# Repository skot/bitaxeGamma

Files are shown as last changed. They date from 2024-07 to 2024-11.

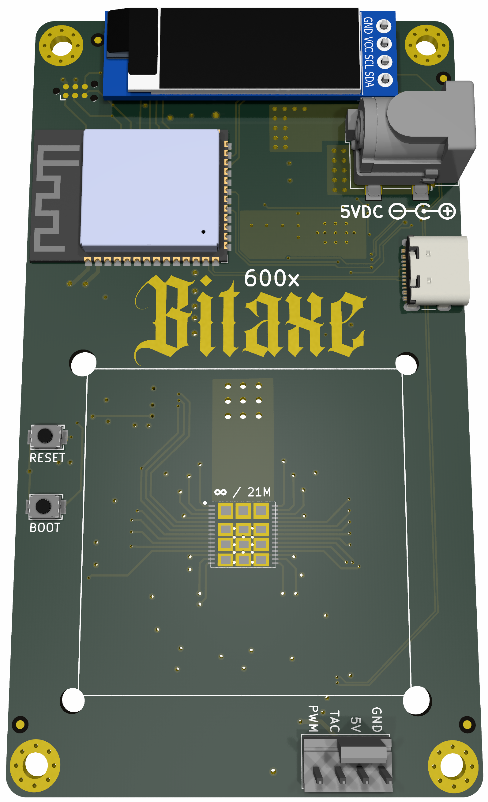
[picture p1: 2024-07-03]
doc/render.png

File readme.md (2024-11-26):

```
Open Source is Intrinsic to Bitcoin
```
# The bitaxeGamma
bitaxe is a fully open source Bitcoin ASIC miner aimed at decentralizing mining. bitaxeGamma is the 5th major revision of the bitaxe that now includes the BM1370 ASIC from the Antminer S21 Pro

bitaxeUltra assembled

## Goals
- **Easy**: Just plug it in and mine Bitcoin over WiFi. No external computer needed.
- **Practical**: low cost, low noise, low power, low maintenance. You can run this at home.
- **ASIC Power**: High efficiency and hashrate, based on the latest and greatest Application Specific Integrated Circuits.
- **Versatile**: Mine to any StratumV1 pool, Lottery mine, Solo mine, Or hack it to do whatever you want.
- **Bitcoin Ethos**: Fully open source, permissionless and decentralized to support the worldwide freedom money.

## ASIC
At the heart of the bitaxeGamma is a BM1370 Bitcoin mining ASIC from the Antminer S21 Pro from Bitmain. It's not open source.

- Bitmain claims the BM1370 has 15 J/TH efficiency. We can get pretty close to that with the BitaxeGamma
- The Antminer S21 Pro has a nominal hashrate of 234 TH/s. There are 3 hashboards with 65 chips each, for a total of 195 chips. The bitaxeGamma has a single one of these chips. That means _about_ 1.2 TH/s per bitaxeGamma. Initial testing looks good!
- The BM1370 is brand new and isn't available individually yet. The best place to get these chips is right out of a S21 Pro.
- The BM1370 has a different footprint and pinout from the BM1368, BM1366, BM1397 and BM1387 in previous bitaxe.

## Current Status
- BitaxeGamma 600 is working well and has been released!
- In addition to higher hashrate, the Gamma also uses more power. Please pay attemtion to hash frequency and voltage settings as it's much easier to overheat, especially when using the stock heatsink and fan.
- BM1370 firmware support has been added to [esp-miner](https://github.com/skot/esp-miner)
- Be sure to check the [HW issues](https://github.com/skot/bitaxe/issues) for known bugs, reworks and errata.
- This is an _advanced_ build! You can do it, but if you're not looking for a project, it might be best to buy one pre-assembled from one of the [many sellers](https://bitaxe.org/legit.html). Check [Skot's method](assembly.md) of hand assembling PCBs.

## PCB Hardware
This repo contains all of the design files for the PCB. [KiCAD](https://www.kicad.com) software is used. There is a BOM file for all of the components that get soldered to the PCB. 

- Order PCBs from your favorite PCB shop, like [JLCPCB](https://jlcpcb.com), [SeeedStudio](https://www.seeedstudio.com/fusion_pcb.html), or [PCBWay](https://www.pcbway.com)
    - Gerbers are in the `Manufacturing Files` dir. PCBs are 4-layer, 6mil trace/space and 0.3mm hole compatible. 1oz outer / 0.5oz inner layer thickness works well.
    - Make sure to order stencils too. These are the "paste" layers in the gerbers folder. one for top and one for bottom.
- All PCB parts except the ASIC are available from [DigiKey](https://www.digikey.com/en/products) and others. You can find Digikey part numbers on the DK tab of the BOM

## Extra Hardware
There are a few other hardware components that are needed for a complete bitaxe.

- **Heatsink**
	- [40x40mm heatsink and 5V fan](https://www.aliexpress.com/item/2251832861666365.html) from a random AliExpress seller. The fans are crap, but the heatsinks are good.  
- **Fan**
	- You **must** have active cooling on the bitaxe. The heatsink alone is not enough.
	- The Bitaxe has a connector for a 4pin, 5V PWM fan. 40mm square, 20mm thick fans work nicely with the suggested heatsink. Make sure to get a 5V fan! 12V spin, but slowly overheating your Bitaxe..
	- Upgrade your fan with the [Noctua NF-A4x10](https://noctua.at/en/nf-a4x10-5v-pwm) 5V 4-Pin fan for a much more pleasant experience.
- **Thermal compound**
	- Use a good quality thermal compound between the heatsink and ASIC. [Thermal Grizzly Kryonaut](https://www.amazon.com/Thermal-Grizzly-Kryonaut-Grease-Paste/dp/B011F7W3LU) has been known to work well.  
- **Display**
	- Supports 0.91" SSD1306-based I2C OLED Module. [Example Amazon seller](https://www.amazon.com/gp/product/B08ZY4YBHL). Make sure to get the male pins to interface with the Bitaxe PCB. 
- **Power Supply**
	- **5V DC Only!** Anything else will damage the Bitaxe. Be careful and double-check your power supply is 5V. Many other voltage power supplies use the same connector.
	- The power supply needs to supply in excess of 4A (20W) and not drop below 5V. Often times you have to use a power supply rated for 25-30W to get this!
 		- The [Meanwell GST60A05-P1J](https://www.digikey.com/en/products/detail/mean-well-usa-inc/GST60A05-P1J/7703709) at 30 Watts is the cadillac of 5V PSUs and is working well with the Gamma.  
	- The bitaxe uses a 5.5x2.1mm, center-positive barrel jack. 5.5x2.5mm plugs have been known to work.
- **Stand**
	- The PCB has corner mounting holes. You're going to want a stand to mount your Bitaxe. Many excellent 3D printed designs are available.

## Firmware
- The [ESP-Miner](https://github.com/skot/ESP-Miner) has initial support for the BM1370 ASIC. Improvements are ongoing.

### ESP32 Programming Requirements
- As of the bitaxeUltra, all ESP32 programming is done through a USB-C cable and connector on the bitaxe. See [ESP-Miner](https://github.com/skot/ESP-Miner) for more details.

## More Information
- Project page at [bitaxe.org](https://bitaxe.org)
- [Open Source Miners United](discord.gg/osmu) Discord chat
- [building.md](building.md) for PCB ordering tips
- [assembly.md](assembly.md) for assembly tips

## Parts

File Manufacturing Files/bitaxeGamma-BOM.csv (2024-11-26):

Qty | Reference | Value | PARTNO | DK | LCSC | DNP
1 | C6 | 4700pF | GRM155R71E472KA01D | 490-1309-1-ND
1 | C9 | 2200pF | GRM155R61H222KA01D | 490-8257-1-ND
1 | C10 | 4.7uF | GRM155R61A475MEAAD | 490-14306-1-ND
1 | C11 | 1000pF | CC0805KRX7R9BB102 | 311-1127-1-ND
1 | C13 | 100pF | 885012005013 | 732-7431-1-ND
1 | C50 | 470pF | CL05B471KB5NNNC | 1276-1566-1-ND
24 | C1 C5 C7 C21 C22 C23 C26 C27 C28 C30 C31 C32 C33 C34 C35 C36 C39 C40 C41 C42 C44 C45 C46 C48 | 1uF | EMK105BJ105MV-F | 587-5514-1-ND
3 | C14 C15 C16 | 22uF | GRM21BR61A226ME44L | 490-10746-1-ND
5 | C17 C18 C19 C20 C43 | 100uF | CL31A107MQHNNNE | 1276-1782-1-ND
2 | C2 C24 | 10uF | CL21A106KOQNNNE | 1276-1096-1-ND
3 | C3 C4 C51 | 47uF | CL32A476KOJNNNE | 1276-3376-1-ND
10 | C8 C12 C25 C29 C37 C38 C47 C49 C52 C53 | 0.1uF | CL05A104KO5NNNC | 1276-1234-1-ND
1 | J1 | 54-00164 | 54-00164 | 839-54-00164CT-ND | C431534
1 | J5 | USB_C_Receptacle_USB2.0 | USB4105-GF-A | 2073-USB4105-GF-ACT-ND
1 | J6 | Conn_01x04 | 0470531000 | WM4330-ND
1 | J7 | Conn_01x04
1 | L1 | 300nH | SLC1175-301MEC
1 | R1 | 8.25k | RC0402FR-078K25L | 311-8.25KLRCT-ND
1 | R5 | 14.7k | RC0402FR-0714K7L | YAG2984CT-ND
1 | R6 | 0 | RC0402JR-070RL | 311-0.0JRCT-ND
1 | R8 | 3.74k | RC0402FR-073K74L | 311-3.74KLRCT-ND
1 | R9 | 11.8k | RC0402FR-0711K8L | YAG2958CT-ND
1 | R10 | 68.1k | RC0402FR-0768K1L | YAG3213CT-ND
1 | R11 | 10 | RC0402FR-0710RL | 311-10.0LRCT-ND
1 | R12 | 1 | CSR1206FT1R00 | CSR1206FT1R00CT-ND
1 | R19 | 1k | RC0402FR-071KL | 311-1.00KLRCT-ND
1 | R21 | 20k | RC0402FR-0720KL | 311-20.0KLRCT-ND
1 | R24 | 5.6k | RC0402FR-135K6L | 13-RC0402FR-135K6LCT-ND
2 | R13 R14 | 49.9 | RC0402FR-0749R9L | 311-49.9LRCT-ND
4 | R15 R16 R17 R25 | 10k | RC0402JR-0710KL | 311-10KJRCT-ND
2 | R22 R23 | 100 | RC0402FR-07100RL | 311-100LRCT-ND
2 | SW1 SW2 | GT-TC029B-H025-L1N | CS1213AGF260 | 2449-CS1213AGF260CT-ND
1 | U2 | TPS546D24ARVFR | TPS546D24ARVFR | 296-TPS546D24ARVFRCT-ND
1 | U3 | RT9080-33GJ5 | RT9080-33GJ5 | 1028-1509-1-ND
1 | U4 | ESP32-S3-WROOM-1 | ESP32-S3-WROOM-1-N16R8 | 1965-ESP32-S3-WROOM-1-N16R8CT-ND
1 | U5 | MCP1824T-1202E/OT | MCP1824T-1202E/OT | MCP1824T-1202E/OTCT-ND
1 | U6 | MCP1824T-0802E | MCP1824T-0802E/OT | MCP1824T-0802E/OTCT-ND
1 | U7 | 25MHz | SX3M25.000E20F30THN |  | C5137262
1 | U8 | BM1370_mode1
1 | U9 | SN74AVC4T774 | SN74AVC4T774PWR | 296-24739-1-ND
1 | U10 | EMC2101 | EMC2101-R-ACZL-TR | EMC2101-R-ACZL-CT-ND

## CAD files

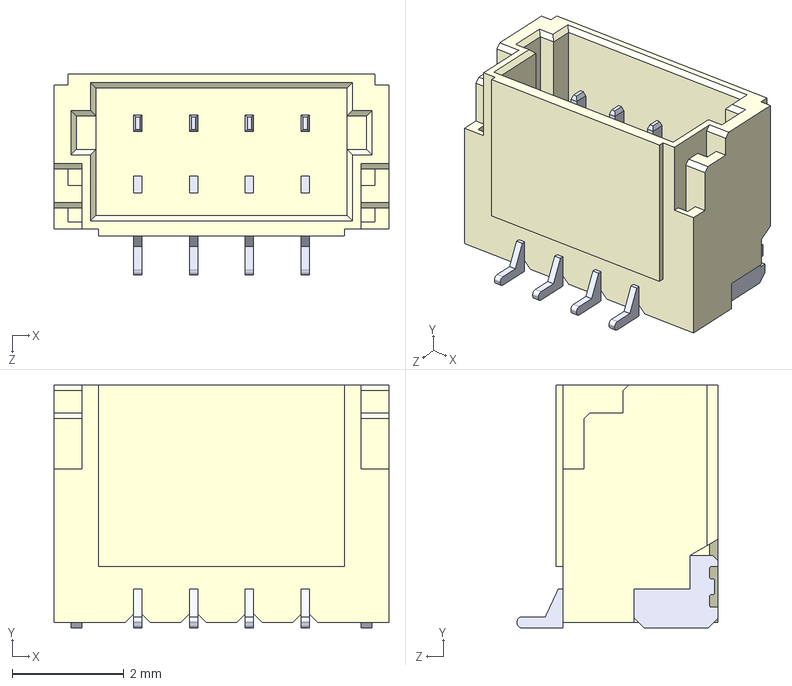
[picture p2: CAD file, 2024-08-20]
3d/BM04B-SRSS-TBT(LF)(SN)--3DModel-STEP-56544.STEP
6.00 x 4.35 x 3.60 mm

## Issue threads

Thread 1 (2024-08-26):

Components

marplukiwi, 2024-08-26:
Please check
The R18 and R19 are shown in the BOM list but the R18 is missing in the KiCAD 3D model. Does this have to be installed or not?

marplukiwi, 2024-08-26:
I noticed this in version 601 not 600

austrisv, 2024-10-07:
R18 in the 600 version's schematics is marked as DNP (Do Not Place). I guess it's a glitch in the generated BOM file.
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

austrisv, 2024-10-07:
Duplicate of https://github.com/skot/bitaxeGamma/issues/5

Closed 2025-03-03.

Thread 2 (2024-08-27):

Wrong display connector

marplukiwi, 2024-08-27:
The display Connector NPTC041KFXC-RC in the BOM File is wron

marplukiwi, 2024-08-27:
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

yellowpi, 2024-09-19:
And what is the truth? Did you find out?

yellowpi, 2024-09-19:
> 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

And what is the truth? Did you find out?

yellowpi, 2024-09-19:
> The display Connector NPTC041KFXC-RC in the BOM File is wron

And what is the truth? Did you find out?

marplukiwi, 2024-09-19:
I soldered the display directly to the PCB without a connector. This is also better because the display only has a small distance to the PCB and cannot bend.

yellowpi, 2024-09-19:
> I soldered the display directly to the PCB without a connector. This is also better because the display only has a small distance to the PCB and cannot bend.

Hello, you can use the screen reinforcement in the link below by printing it from your 3D printer and use it compatible with your screen.
 with love.

link

https://github.com/IamGPIO/Bitaxe201-204-ScreenSaver

skot, 2024-09-19:
Hey, sorry about that. There is no connector needed on the PCB for the display. Get a OLED with male pins and it will friction-fit into the holes on the Bitaxe PCB -- or you can solder them in.

I'll get this fixed on the BOM

yellowpi, 2024-09-19:
> Hey, sorry about that. There is no connector needed on the PCB for the display. Get a OLED with male pins and it will friction-fit into the holes on the Bitaxe PCB -- or you can solder them in.
>
> I'll get this fixed on the BOM

Mr. skot, is there no need to buy this? Should we buy this component?

skot, 2024-09-19:
J3 part number has been removed from schematic and BOM. There is no need for a part on this footprint.

Closed 2024-09-19.

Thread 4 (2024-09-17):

R2, R3, R4 and R7

Alexgtc, 2024-09-17:
Does anyone know why the list of materials does not show the resistances r2, r3, r4 and r7 and in the gerbers yes? Can the plate be mounted leaving those resistors unmounted?

marplukiwi, 2024-09-19:
According to the circuit diagram, the resistors are not needed
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

Alexgtc, 2024-09-19:
Ok, so leaving those resistors without mounting, the gamma bitaxe should work without problems, right?

marplukiwi, 2024-09-19:
If the documentation, i.e. the circuit diagram, is correct then yes. But I cannot confirm this.

Alexgtc, 2024-09-19:
Ok, I'll try to mount it without those resistances to see if it works. Thank you for the help.

yellowpi, 2024-09-19:
@skot dear skot, what do you say about this?

skot, 2024-09-19:
@marplukiwi is correct, R2, R3, R4 and R7 are DNP meaning "Do Not Place".

marplukiwi, 2024-09-20:
@skot and R18 DNP or not? R18 is in the BOM but crossed out in the circuit diagram.

skot, 2024-09-20:
The red X in KiCad means DNP

Closed 2024-09-19.

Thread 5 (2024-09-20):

R18

Alexgtc, 2024-09-20:
R18, is in the list of materials but it is crossed out in the diagrams. Should we install it in version 600?

skot, 2024-09-20:
Yes the red X in KiCad schematic means DNP

Closed 2024-09-20.

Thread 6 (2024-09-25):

unused level shifter inputs should not be left floating.

skot, 2024-09-25:
From the [SN74AVC4T774 datasheet](https://www.ti.com/lit/ds/symlink/sn74avc4t774.pdf)

> Since this device has CMOS inputs, it is very important to not allow them to float. If the inputs are not driven to either a high VCC state, or a low-GND state, an undesirable larger than expected ICC current may result. Since the input voltage settlement is governed by many factors (for example, capacitance, board-layout, package inductance, surrounding conditions, and so forth), ensuring that they these inputs are kept out of erroneous switching states and tying them to either a high or a low level minimizes the leakage-current.

We need to either connect the input B4 to ground, or tie DIR4 high to make B4 an output.

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

skot, 2025-04-29:
this has been fixed.

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

Closed 2025-04-29.

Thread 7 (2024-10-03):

Switch from SN74AVC4T774 (AVC) SN74AXC4T774 (AXC)

benjamin-wilson, 2024-10-03:
The SN74AXC4T774  is a drop in replacement - I would also suggest using the WQFN package as it is more stocked and 2/3 the cost.
"The AXC is faster, has a wider supply range and guarantees glitch free power up."

https://www.ti.com/lit/ds/symlink/sn74axc4t774.pdf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

person65278, 2025-02-02:
so what would happen if i swapped  it to SN74AXC4T774PWR from digi key. just unsoldered the old and slapped it on there?

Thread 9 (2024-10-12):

DFM - Increase pad size of barrel plug and inductor

benjamin-wilson, 2024-10-12:
Increase the pad size of these two elements to provide more solder to the component - the barrel plug can be removed with a strong push of the thumb currently.

4xmajor, 2024-10-15:
I have a few more suggestions/observations regarding these these parts...

1. Due to availability issues, I switched the barrel jack suggested in the schematic (54-00164) out for  PJ-036AH-SMT-TR.

The pads and contacts are far more substantial than the 54-00164, and it is far more abundantly available (on DigiKey at least)... may be a better choice in general?

2. I also have had to switch out the suggested inductor (SLC1480-301ML) to 104CDMCCDS-R30MC due to availability issues.

The package size and footprint of the SLC1480-301ML is very awkward. It is basically unique among inductors which satisfy the calculated necessary values for L, Isat and Irms according to the TPS546D24 datasheet (8.2.2.3). (I got: L = 300nH, Irms = 35.12A, Isat(peak) = 40.02A)

The package size of 104CDMCCDS-R30MC seems to be very common for these attributes at 11.5mm x 10mm. This might be a better choice for the schematic as it promotes drop-in replacements and also happens to require larger solder pads for sturdiness.

skot, 2024-10-21:
> I have a few more suggestions/observations regarding these these parts...
>
> 1. Due to availability issues, I switched the barrel connector suggested in the schematic (54-00164) out for  PJ-036AH-SMT-TR.

funny story; we switched to 54-00164 previously because PJ-036AH-SMT-TR went 100% out of stock everywhere. It's wack-a-mole with these things.

BitMaker-hub, 2024-10-22:
I also think 54-00164 is more standard, we can go furder and find compatible parts to it also. Sure there are more out there

benjamin-wilson, 2024-11-02:
Did this on 602 - sent to fab for verification

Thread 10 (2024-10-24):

BOM change U7

BitMaker-hub, 2024-10-24:
Hi Skot,

Seems previously used crystal 25,0-JO32-B-1V3-1-T1-LF is out of voltage range currently used in GAMMA.
BOM still says 25,0-JO32-B-1V3-1-T1-LF ofr U7.

Can you change it to SX3M25.000E20F30THN, to avoid others mistake?

skot, 2024-10-24:
This is a really unfortunate CSV parsing error. I've fixed it in the 600 release already. I think it might still need to be fixed in the unreleased branches

Closed 2025-03-03.

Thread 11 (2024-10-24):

Suggestion - TVS diode at 5V input

BitMaker-hub, 2024-10-24:
Even could not be necessary, this is recommended to protect bitaxe from plug/unplug transients.
This should be on the power supply, but you can't always guarantee.

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

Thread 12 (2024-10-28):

Some bitaxeGamma builds are overheating at stock settings.

skot, 2024-10-28:
We have reports of some bitaxeGamma 600 builds overheating in a few minutes with recommended stock heatsink and fan, running at stock settings of 525MHz / 1150mV

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

skot, 2024-10-28:
There are plenty of bitaxeGamma 600/601/602 that are not overheating at stock settings, including the dozen or so I have used.

skot, 2025-03-03:
This has been fixed with better temp diode tuning on the EMC2101

Closed 2025-03-03.

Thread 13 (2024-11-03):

Determine proper ASIC temp diode series resistance

skot, 2024-11-03:
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

R22 and R23 are series resistors inline with the ASIC temp diode, used for measuring the ASIC die temp.

The [EMC2101 datasheet](https://ww1.microchip.com/downloads/aemDocuments/documents/MSLD/ProductDocuments/DataSheets/EMC2101-Data-Sheet-DS20006703.pdf) says;

> Parasitic resistance in series with the external diodes will limit the accuracy obtainable from temperature measurement devices. The voltage developed across this resistance by the switching diode currents cause the temperature measurement to read higher than the true temperature. Contributors to series resistance are Printed Circuit Board (PCB) trace resistance, on die (i.e. on the processor) metal resistance, bulk resistance in the base and emitter of the temperature transistor. Typically, the error caused by series resistance is +0.7°C per ohm. Temperature errors caused by up to 100Ω of series resistance are automatically corrected.

Is 100 Ohms in series the right call? Maybe we don't need _any_ series resistance here? Does this have something to do with #12 ?

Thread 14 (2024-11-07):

BOM file missing some resistors

sospcie, 2024-11-07:
BOM file missing some resistors, like R2 , R3, R4, R7

austrisv, 2024-11-08:
check https://github.com/skot/bitaxeGamma/issues/4 - they are DNP, thus not placed in the BOM (as the resistors are not needed)

Closed 2025-03-03.

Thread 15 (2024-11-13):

some ASIC die temperature readings are incorrect

skot, 2024-11-13:
On some BM1370 units the die temperature readings collected by the EMC2101 are incorrect. We've seen readings both too high and too low. Both at idle and while mining.

Initially it appears some units are affected and others are not.

skot, 2024-11-13:
might be related to #13

skot, 2025-03-04:
This has been fixed with better temp diode tuning on the EMC2101

Closed 2025-03-04.

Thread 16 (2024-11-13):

Fluctuating ASIC die temperature readings.

skot, 2024-11-13:
A few users have reported wildly fluctuating ASIC die temperature readings, sometimes 20ºC or more between individual temperature readings.

skot, 2024-11-13:
from OSMU Discord user `usekevin`:
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

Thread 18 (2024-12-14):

Hole Pattern for heatsink is not symmetric

ogbitcoin, 2024-12-14:
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

skot, 2025-03-03:
This is a bug. They should be symmetric.

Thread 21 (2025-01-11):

Failure to find select PLL frequencies when overclocking

jtsmith0101, 2025-01-11:
Investingating higher frequencies.  On startup, there are several frequency failure messages above 750 MHz.  Please see attached.

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

Does this mean my hashing on a 600 gamma is capped?  Can it be fixed with a new firmware or does it indicate a hardware anomaly?

My firmware is v2.4.4

skot, 2025-03-03:
No your frequency is not capped. Due to the way (we think the) BM1370 registers work, not all frequencies are available. All that really matters here is that it can find the last one.

Closed 2025-03-03.

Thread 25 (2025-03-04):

Add pullup resistors on I2C/SMBus pins

skot, 2025-03-04:
SDA and SCL data pins need a pullup resistor to 3.3V. The TPS546 SMB_ALRT should also have this. 4.7k should be good.

sz4bi, 2025-05-14:
I can not find the SMB_ALRT resistor anywhere in the modified files. Are we talking about the TPS546 PMB_ALRT pin on the schematics?

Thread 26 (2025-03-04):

Improve BM1370 footprint.

skot, 2025-03-04:
The GND power pad is a little too big, and VDD too small. Also revisit the 0.503mm pin pitch. Should it be 0.50mm?

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

benjamin-wilson, 2025-03-05:
Fixed in this commit:
713e3acc43809ab757ac48d10b03d2d3deff822a
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

Closed 2025-03-16.

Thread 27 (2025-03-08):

Missing Resistors in BOM and Clarification on DNP Components

loden-nodeway, 2025-03-08:
To whom it may concern,

I noticed that the BOM list is missing several resistors: R2, R3, R4, R7, R18, R20, R22, and R23. After checking the schematic, I found that R2, R3, R4, and R7 are marked as DNP (Do Not Place). However, R18, R20, R22, and R23 do not appear to be DNP.

Could you please confirm if my observation is correct? Also, I would appreciate it if you could provide the component names for these resistors.

Thank you for your attention to this matter.

Best regards,
Loden.

Marcocanc, 2025-03-16:
+1

skot, 2025-03-16:
R2, R3, R4, R7, R18 are DNP on the schematic.
R20 doesn't exist
R22 & R23 are on the BOM: https://github.com/bitaxeorg/bitaxeGamma/blob/a325117698b93c3a2e064ae0e7f2b570a8666134/Manufacturing%20Files/bitaxeGamma-BOM.csv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

Closed 2025-03-16.

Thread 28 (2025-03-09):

Wrong part number for J3

adadnc, 2025-03-09:
On the board J3 is shown as a through-hole component while the part number from the schematics lists a NPTC041KFXC-RC, which is an SMD component. Am I wrong here? Either the footprint is wrong or is the part number.

skot, 2025-04-29:
fixed in 4bcb769

Closed 2025-04-29.

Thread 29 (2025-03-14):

Bitaxe Gamma Not Hashing

Kizzle65, 2025-03-14:
I have two Bitaxe Gammas and both setup up exactly the same.  The one is hashing but other will not.  Please help me out.

pinetree1212, 2025-03-14:
I had the same issue. While checking the DASHBoard on AxeOS, I noticed that the input voltage was higher than 5.2V. After replacing the adapter with a Korean-made one instead of a new Chinese one, it started hashing  Accurate voltage supply seems to be important

Kizzle65, 2025-03-14:
So now both of them won't hash. They are running 5.3 and 5.4 volts. Are you saying the voltage needs to be closer to 5.0?

Closed 2025-03-14.

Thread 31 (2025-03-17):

UVLO Voltage divider it set wrong for 5V input

skot, 2025-03-17:
The TPS546D24A UVLO threshold is 2.5V. For this to trigger at about 4.5VIN, R8 should by 15k (not 3.74k)

skot, 2025-03-18:
Er, maybe not. I think I was looking at the wrong threshold (there are several). The ENuvlo threshold is actually 1.05V, making the UVLO for our current voltage divider set at 4.36V

Closed 2025-03-18.

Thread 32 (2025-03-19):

PCB mounting holes are a bit off

etkaar, 2025-03-19:
They are only off a little bit, but that still can cause problems with custom stands, enclosures and cases:

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

skot, 2025-04-29:
fixed in 4bcb769

Closed 2025-04-29.

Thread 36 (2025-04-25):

ASIC nRST pin should be pulled down

skot, 2025-04-25:
nRST low -> ASIC in reset. this is what we want to be by default.

skot, 2025-04-29:
fixed in 4bcb769

Closed 2025-04-29.

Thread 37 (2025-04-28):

Bitaxe is not detected when connected to a USB-C port

rkuester, 2025-04-28:
A Bitaxe Gamma is not detected when connected to an upstream USB-C port. Presumably, this is due to lack of pull-downs on the Bitaxe's USB-C CC pins. USB Sources detect the attachment of devices through USB-C physical connections by utilizing the CC pins.

I have verified this behavior on both a modern MacBook Air and a Linux server with USB-C ports. Presumably, this would also be an issue with hubs that have USB-C ports facing downstream.

There is no issue when a Bitaxe is connected via a USB-C to USB-A cable, because USB-A ports detect attachment via devices pulling up D+ and or D- (in the Bitaxe's case, internally in the USB controller).

MyOwn2C, 2025-04-28:
Known issue but not fixed.
Only my oldest Ultra works with USB.
All my other Supra (2x) and Gamma (3x) none of them worked with USB.
I just use UART to update if webpage update does not work.

skot, 2025-04-28:
Uuuf, you are totally right. I'm kicking myself for removing these pulldowns a while back. I'll get these put back on in future revs. In the mean time you'll have to use a USB-C to USB-A adapter and cable 😭

I swear I had a USB-C to C cable that magically worked.

skot, 2025-05-12:
- Connect a 5.1 kΩ resistor from CC1 to ground.
- Connect a 5.1 kΩ resistor from CC2 to ground.

skot, 2025-07-03:
I have heard that Bitaxes works on USB-C ports that are not also Thunderbolt ports.

skot, 2025-07-03:
Confirmed adding 5.1k pulldown resistors on CC1 and CC2 on a BitaxeGamma 601 allows it to mount on my MacBook USB-C thunderbolt ports.

skot, 2025-09-10:
Looks like this bug was introduced on 401 hardware. everything prior to that _should_ be unaffected.

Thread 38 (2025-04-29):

Some silkscreen labels on 602 are all wonky

skot, 2025-04-29:
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

skot, 2025-04-29:
fixed in 4bcb769

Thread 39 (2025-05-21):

control the 4bit nonce.

g1ass1, 2025-05-21:
is there a way to control or limit how the device interacts with the mining loop.  specifically, the 4byte nonce in the block header.
I see how this can be done with extra nonce easily.  is the nonce controlled via asci hardware or the code.

skot, 2025-05-21:
there is some rudimentary control over the nonce range that the ASIC rolls through. This is used when the ASICs are in long chains so that they don't duplicate work.

This is the hardware repo, the [esp-miner](https://github.com/bitaxeorg/esp-miner) or even better the [OSMU Discord](https://discord.gg/osmu) would be more appropriate for this discussion.

Closed 2025-05-21.

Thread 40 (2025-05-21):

Bite Gamma

superfastdrop, 2025-05-21:
I have a new Gamma that's not hashing. The only issue I can see is there is 0 measured ASIC voltage. How can this be fixed?

skot, 2025-05-21:
Speak with the seller where you purchased your Bitaxe for support.

Closed 2025-05-21.

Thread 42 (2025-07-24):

Bitaxe Gamma stops working after wifi hickup

cedrickoch, 2025-07-24:
Description:
I've been operating a Bitaxe Gamma for a few weeks now and have encountered a recurring issue where it stops hashing every few days, requiring a restart. When the device enters this state, the web interface also becomes unreachable. I've logged the output from the USB interface, which is attached for review.

Observations:
- The initial part of the log shows everything working smoothly.
- In the middle of the log, there are multiple WiFi resets. It's worth noting that the WiFi repeater is positioned right next to the Bitaxe and is stable.
- The final phase in the log indicates when the Bitaxe stops functioning.

Steps to Reproduce:
- Operate the Bitaxe Gamma over several days.
- Observe the hashing process and periodically check accessibility to the web interface.
- Monitor for an eventual halt in operation and loss of web interface access.

Expected Outcome:
- Continuous hashing and accessible web interface without the need for frequent restarts.
- Actual Outcome: Hashing stops intermittently every few days, requiring a restart, and the web interface becomes unavailable during this period.

Attached Log: Please find the USB interface log attached for further investigation.

[debug.log](https://github.com/user-attachments/files/21402074/debug.log)

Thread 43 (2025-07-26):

BitAxe Gamma with duplicate share.

RoanArraes, 2025-07-26:
I need help with duplicate share in my BitAxe Gamma. I dont know how this happens.

How i can fix this?

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

111 rejected ( all duplicate share)

Log:

₿ (16791238) stratum_task: rx: {"result":false,"error":{"code":22,"message":"duplicate share","data":null},"id":1226}
₿ (16791238) stratum_task: message result rejected: unknown

₿ (17032038) stratum_task: rx: {"result":false,"error":{"code":22,"message":"duplicate share","data":null},"id":1248}
₿ (17032038) stratum_task: message result rejected: unknown

₿ (17147038) stratum_task: rx: {"result":false,"error":{"code":22,"message":"duplicate share","data":null},"id":1260}
₿ (17147038) stratum_task: message result rejected: unknown

Thanks for help.

RoanArraes, 2025-07-27:
I tried tree pools and two have the same duplicate share problem, but the third pool didn't show this problem.

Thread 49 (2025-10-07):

BOM List J1 DC Power Jack Incompatible

lrstolk, 2025-10-07:
I found out the advised J1 - DC Power Jack does actually not meet the requirements.

The CSV BOM list tells me to use LCSC part C431534. This is max 30V 2A. While the README tells me I need a power supply of 5V with 4A, this exceeds the power of what the DC Power Jack can hold.

Any advice of what to do? I already placed a pick and placed order on LCSC.

skot, 2025-10-07:
Uuf, sorry I didn't notice this before. The DigiKey part number is rated for 5.5A I've removed the LCSC part number from the BOM.

Maybe you can contact JLCPCB and have them DNP this part on your build?

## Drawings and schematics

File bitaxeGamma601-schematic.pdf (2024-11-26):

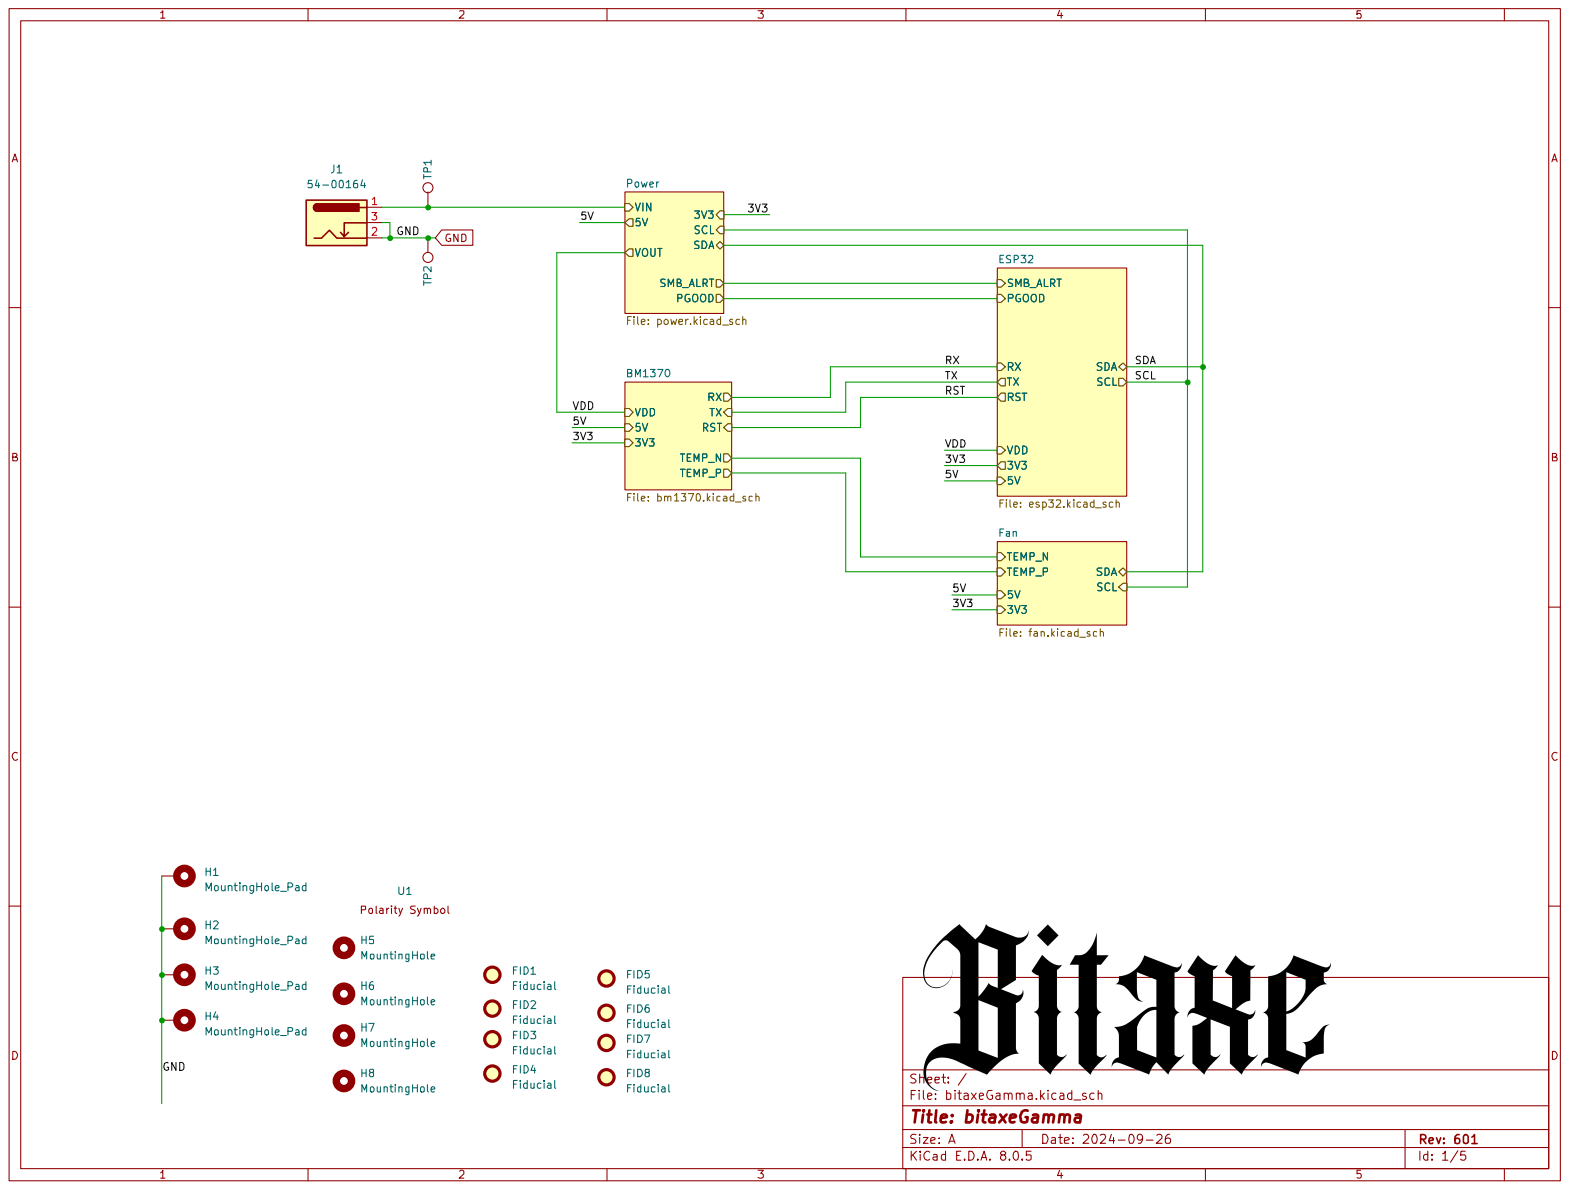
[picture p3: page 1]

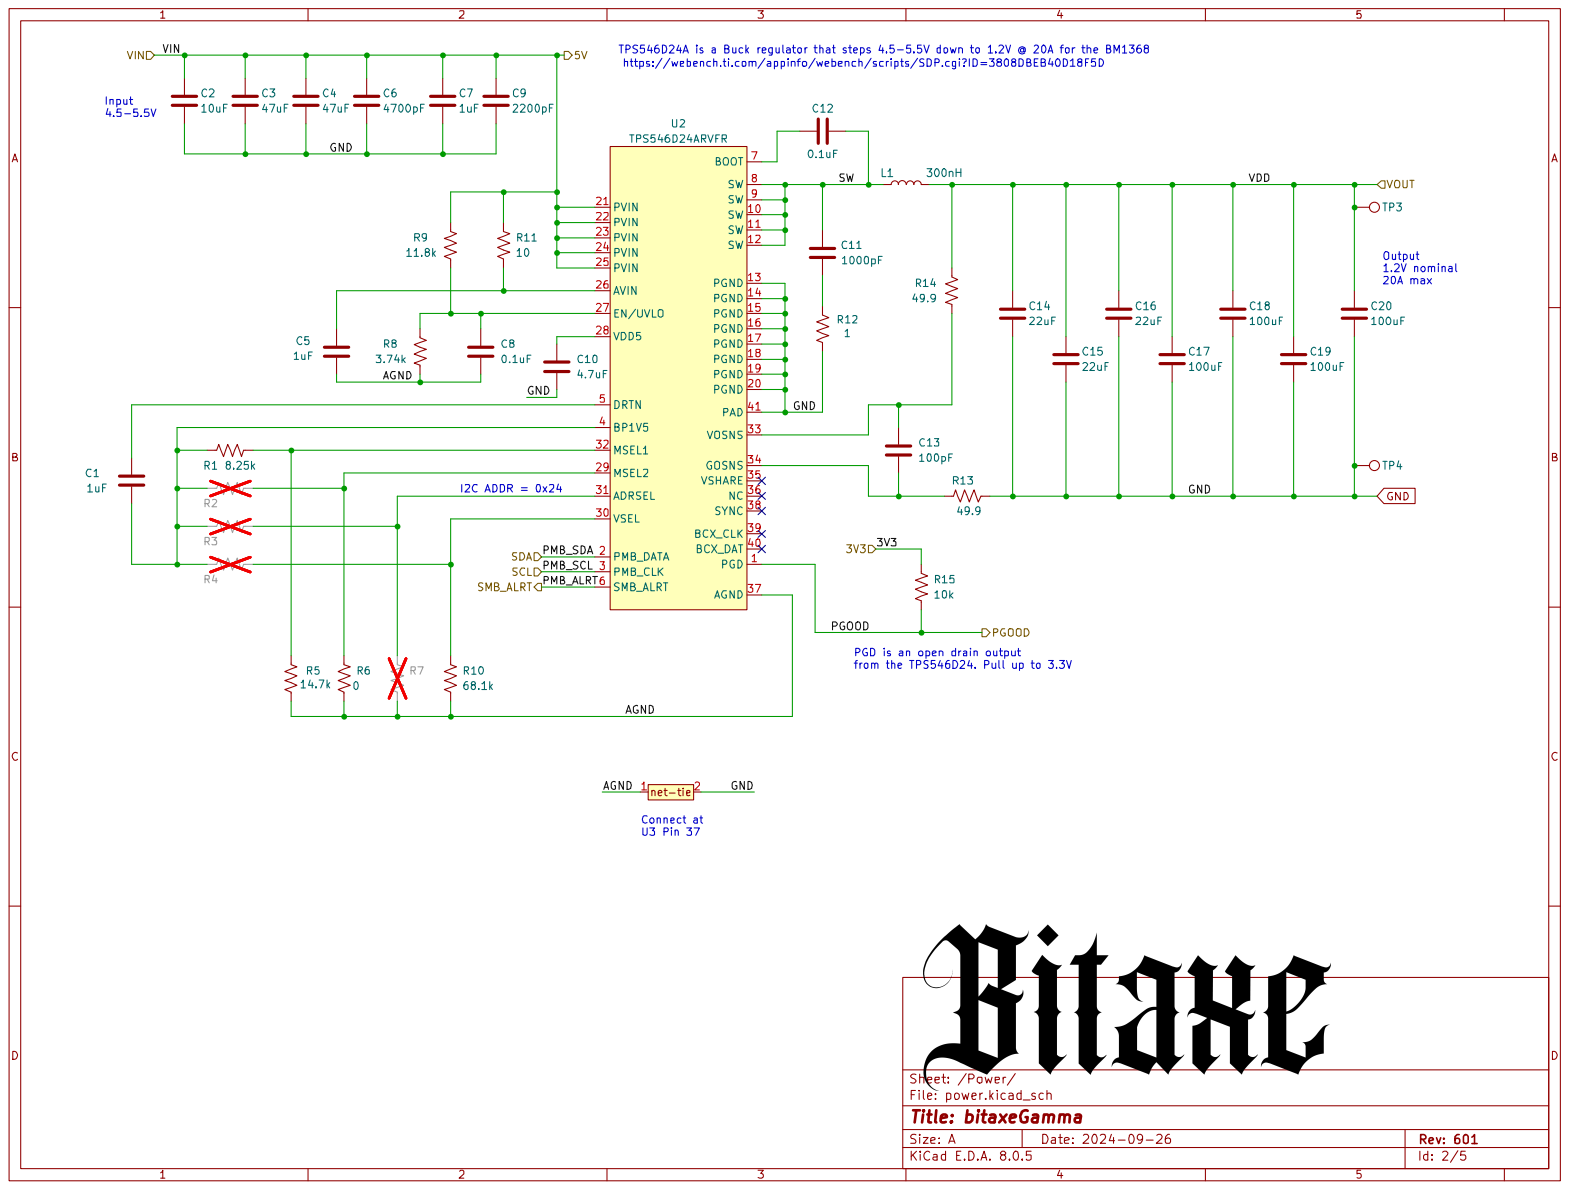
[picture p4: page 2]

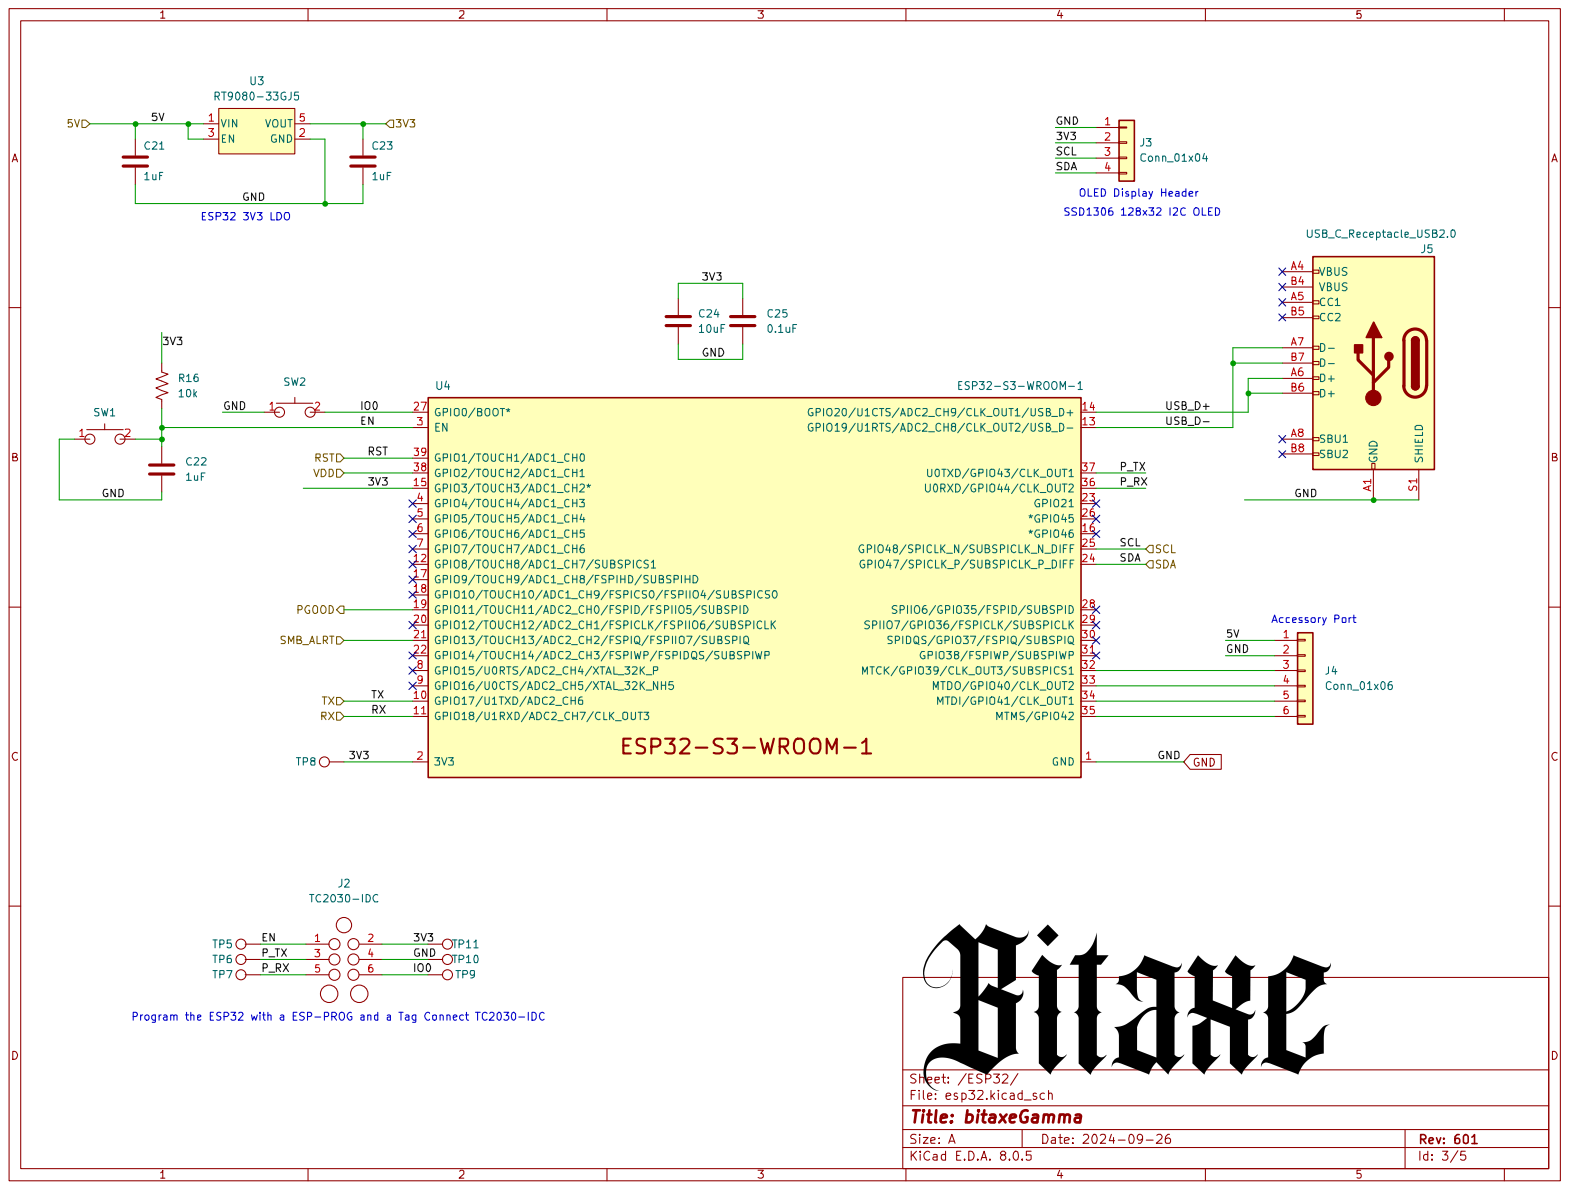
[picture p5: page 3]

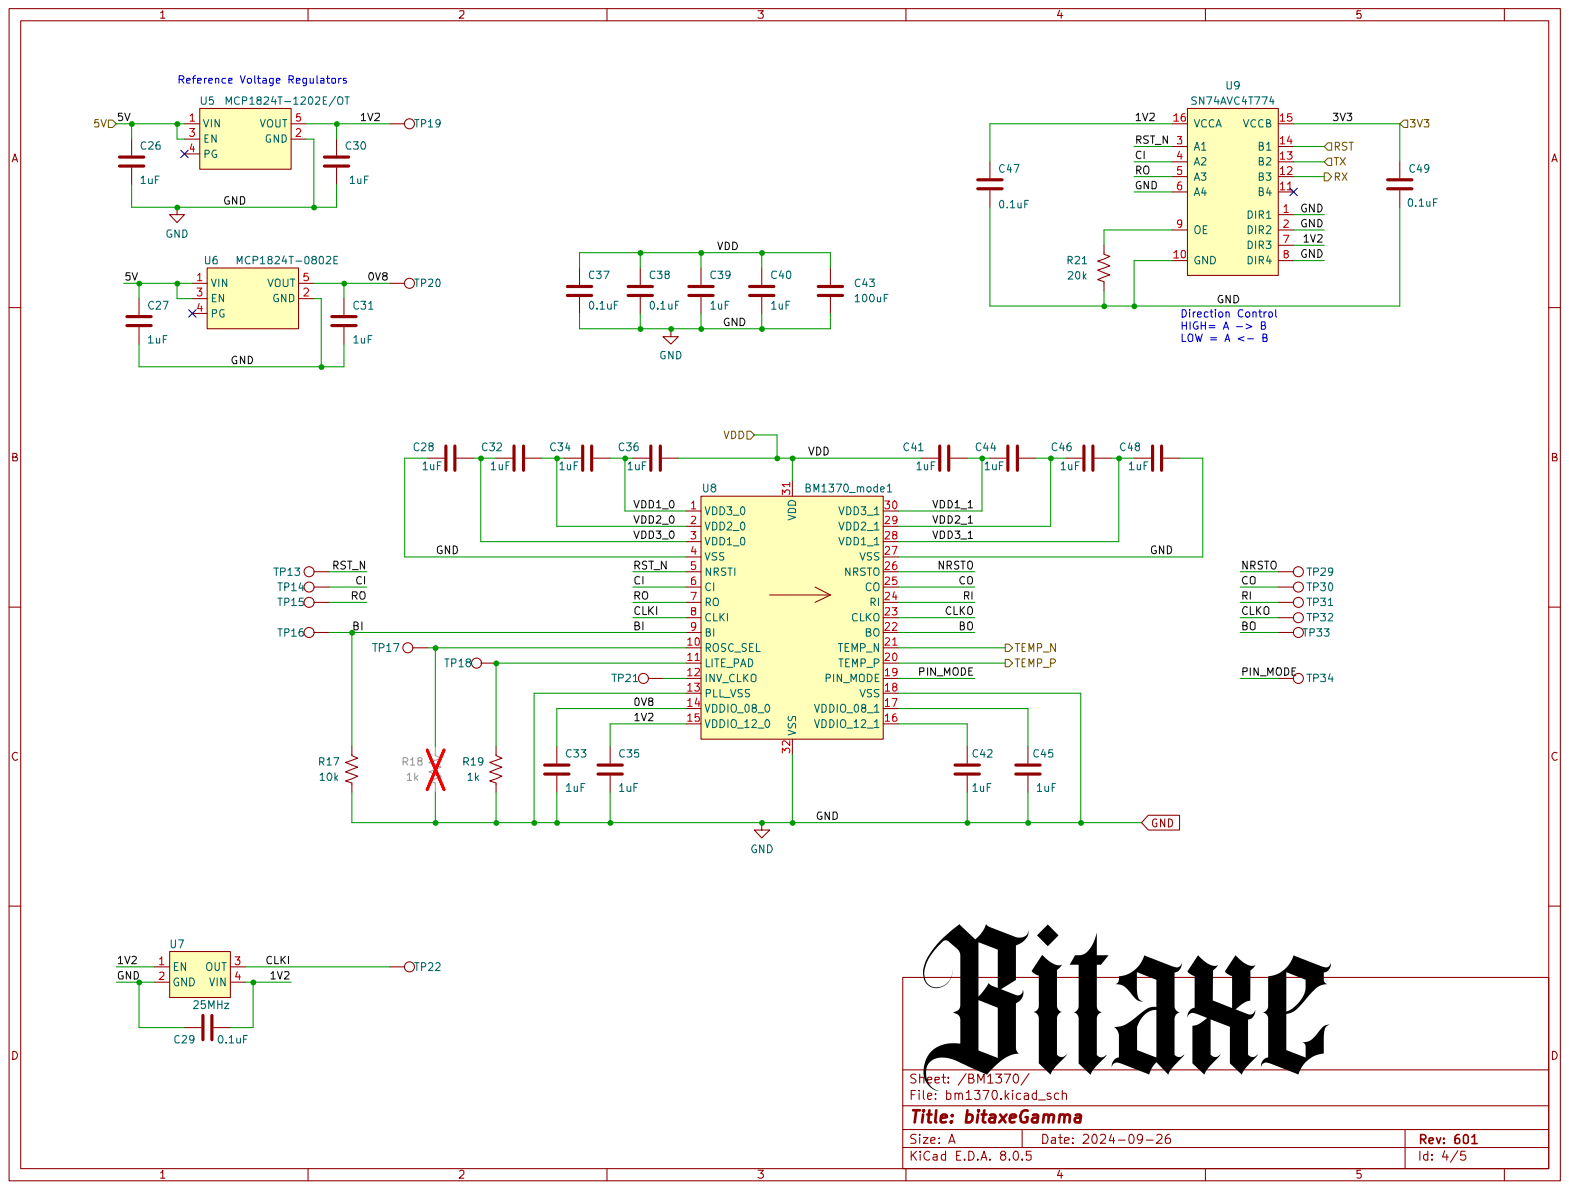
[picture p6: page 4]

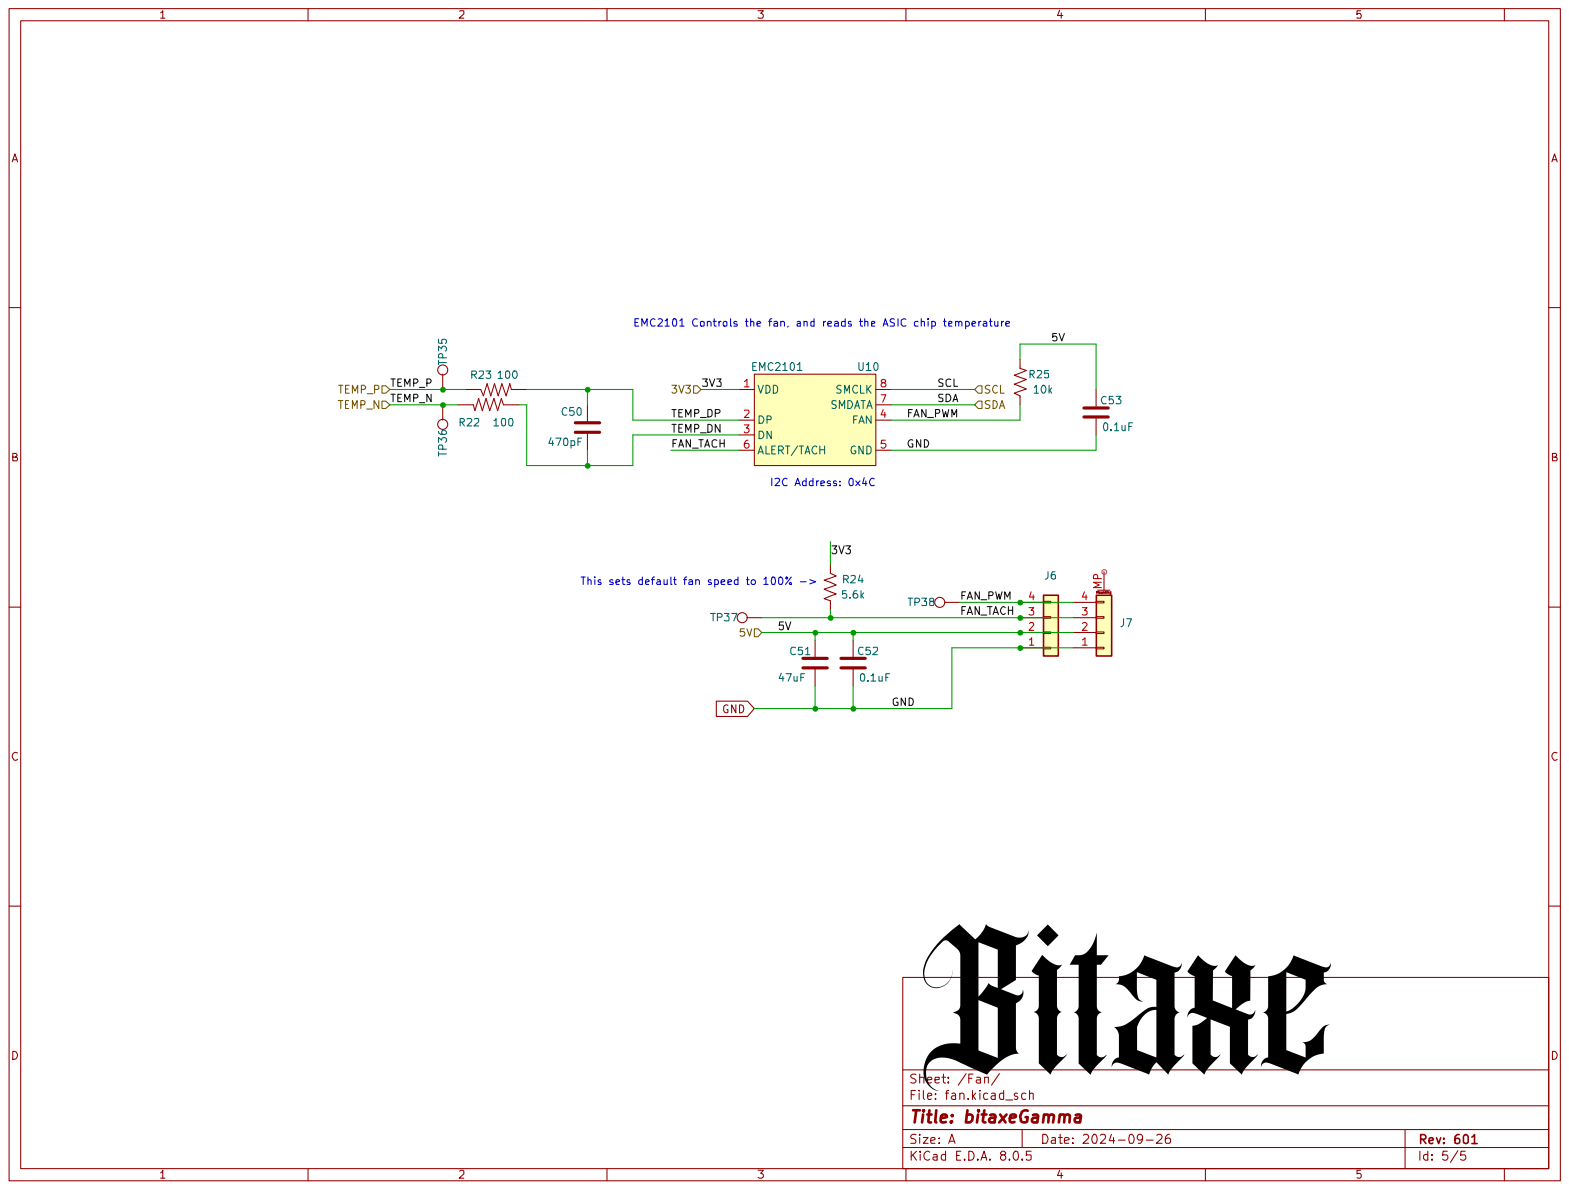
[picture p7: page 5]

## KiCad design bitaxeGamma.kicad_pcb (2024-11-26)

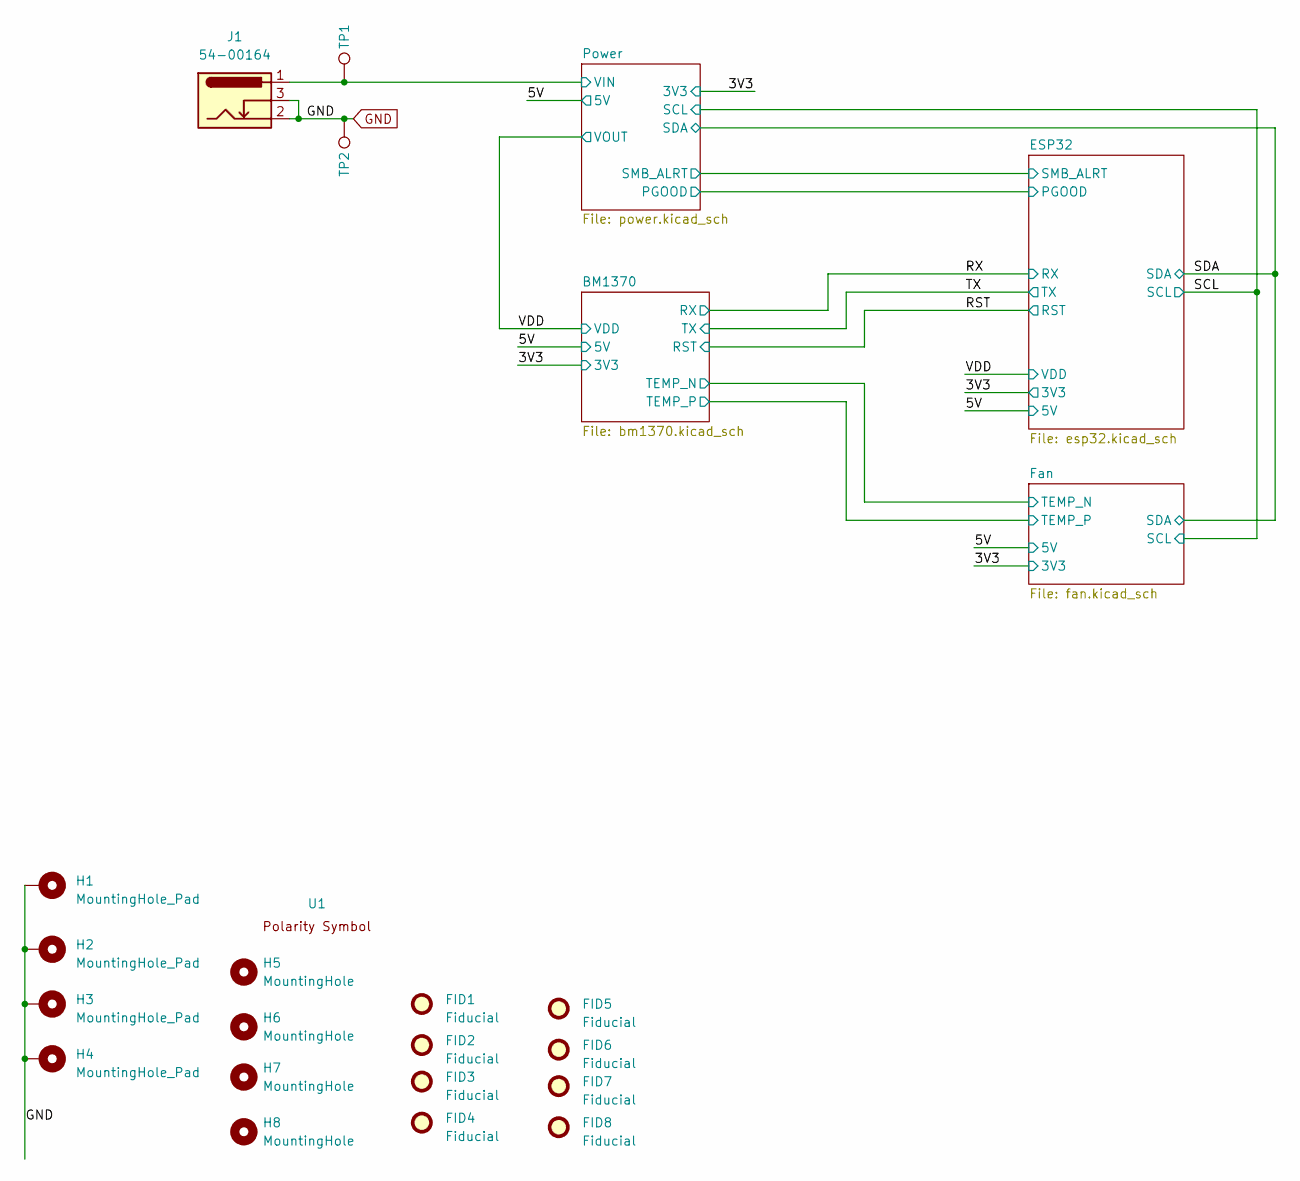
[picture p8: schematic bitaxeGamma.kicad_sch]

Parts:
FID1, FID2, FID3, FID4, FID5, FID6, FID7, FID8: Fiducial; Fiducial_1mm_Mask2mm
H1, H2, H3, H4: MountingHole_Pad; MountingHole_3mm_Pad_Via
H5, H6, H7, H8: MountingHole; MountingHole_3.5mm
J1: 54-00164; TENSILITY_54-00164; PARTNO 54-00164; LCSC C431534
TP1, TP2: TestPoint; TestPoint_Pad_D1.5mm
U1: polarity

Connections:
/5V: J1.1, TP1.1; also elsewhere on the board

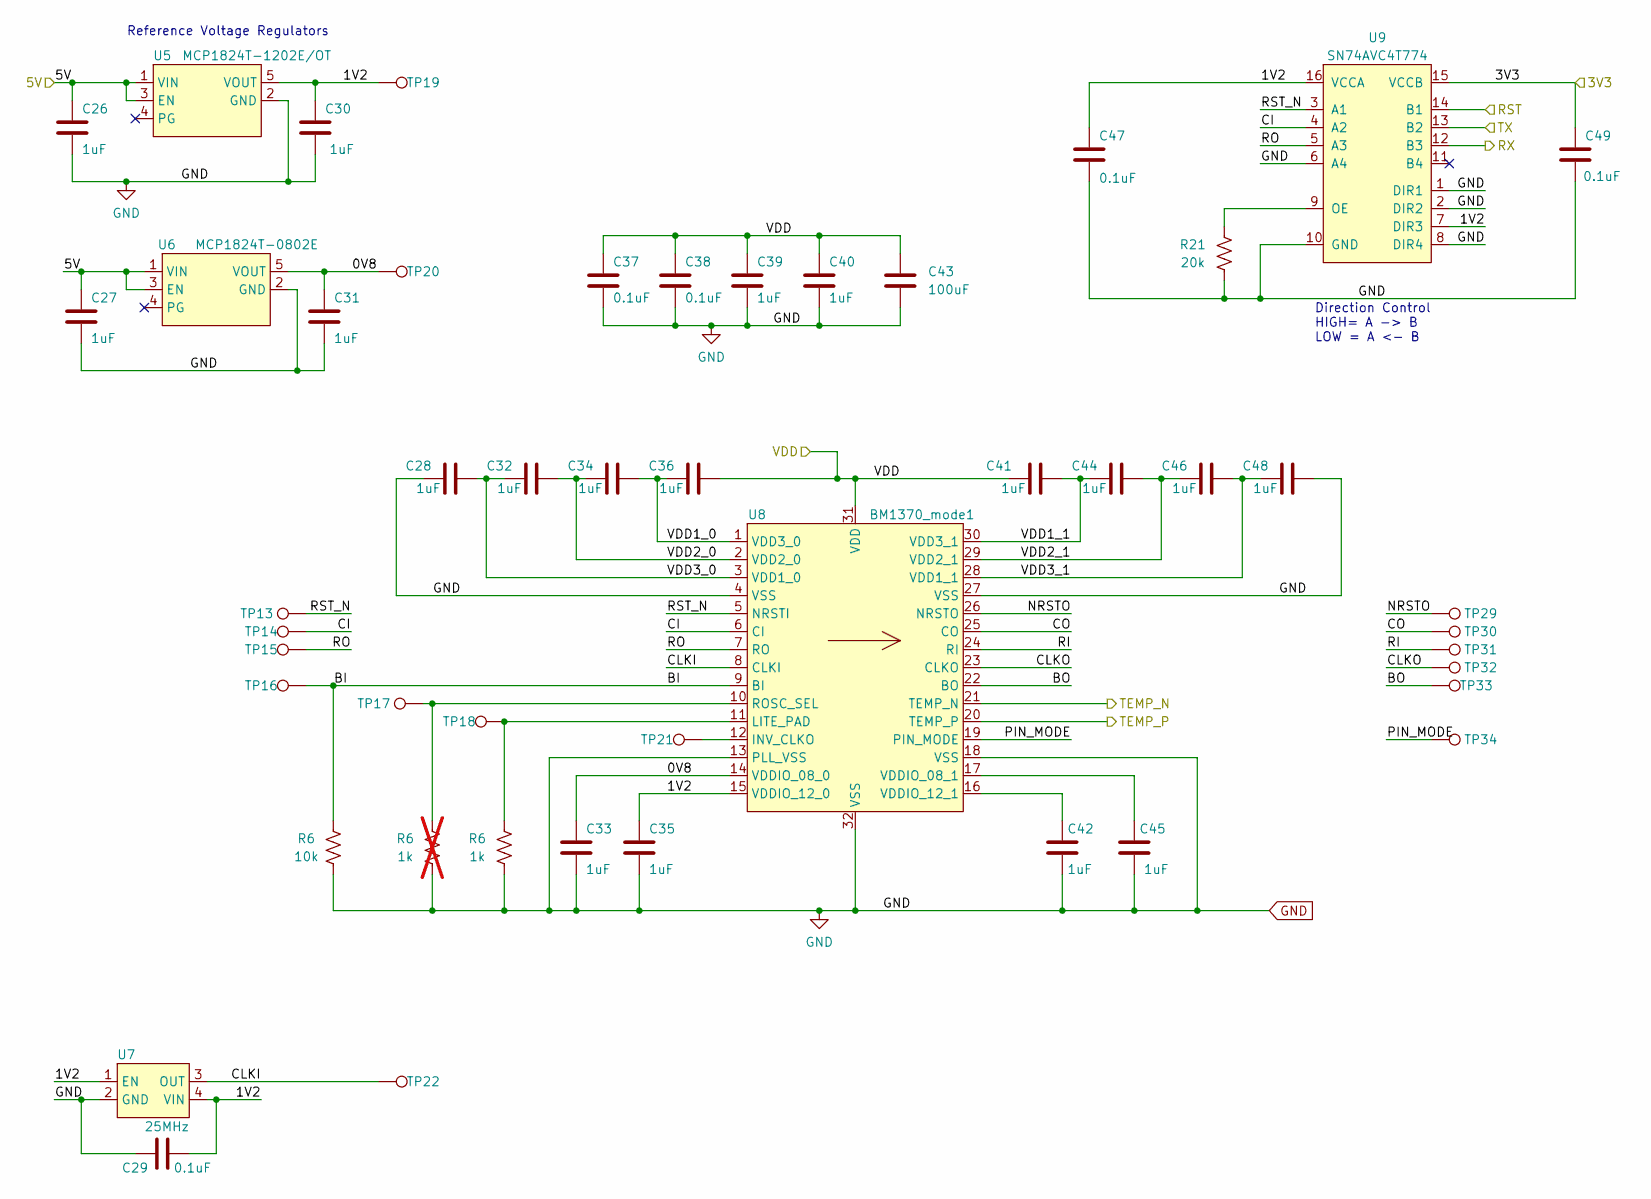
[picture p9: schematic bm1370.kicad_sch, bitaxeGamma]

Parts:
C26, C27, C28, C30, C31, C32, C33, C34, C35, C36, C39, C40, C41, C42, C44, C45, C46, C48: 1uF; C_0402_1005Metric; PARTNO EMK105BJ105MV-F
C29, C37, C38, C47, C49: 0.1uF; C_0402_1005Metric; PARTNO CL05A104KO5NNNC
C43: 100uF; C_1206_3216Metric; PARTNO CL31A107MQHNNNE
R6: 1k; R_0402_1005Metric; PARTNO RC0402FR-071KL; not fitted
R21: 20k; R_0402_1005Metric; PARTNO RC0402FR-0720KL
TP13, TP14, TP15, TP16, TP17, TP18, TP19, TP20, TP21, TP22, TP29, TP30, TP31, TP32, TP33, TP34: TestPoint; TestPoint_Pad_D1.5mm
U5: MCP1824T-1202E/OT; SOT-23-5; PARTNO MCP1824T-1202E/OT
U6: MCP1824T-0802E; SOT-23-5; PARTNO MCP1824T-0802E/OT
U7: 25MHz; SMD3225-4P; PARTNO SX3M25.000E20F30THN; LCSC C5137262
U8: BM1370_mode1; BM1370
U9: SN74AVC4T774; TSSOP-16_4.4x5mm_P0.65mm; PARTNO SN74AVC4T774PWR

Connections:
/3V3: C49.1, U9.15 (VCCB); also elsewhere on the board
/5V: C26.1, C27.1, U5.1 (VIN), U5.3 (EN), U6.1 (VIN), U6.3 (EN); also elsewhere on the board
/BM1370/0V8: C31.1, C33.1, TP20.1, U6.5 (VOUT), U8.14 (VDDIO_08_0)
/BM1370/1V2: C29.2, C30.1, C35.1, C47.1, TP19.1, U5.5 (VOUT), U7.1 (EN), U7.4 (VIN), U8.15 (VDDIO_12_0), U9.7 (DIR3), U9.16 (VCCA)
/BM1370/BO: TP33.1, U8.22 (BO)
/BM1370/CI: TP14.1, U8.6 (CI), U9.4 (A2)
/BM1370/CLKI: TP22.1, U7.3 (OUT), U8.8 (CLKI)
/BM1370/CLKO: TP32.1, U8.23 (CLKO)
/BM1370/CO: TP30.1, U8.25 (CO)
/BM1370/NRSTO: TP29.1, U8.26 (NRSTO)
/BM1370/PIN_MODE: TP34.1, U8.19 (PIN_MODE)
/BM1370/RI: TP31.1, U8.24 (RI)
/BM1370/RO: TP15.1, U8.7 (RO), U9.5 (A3)
/BM1370/RST_N: TP13.1, U8.5 (NRSTI), U9.3 (A1)
/BM1370/VDD1_0: C34.2, C36.1, U8.1 (VDD3_0)
/BM1370/VDD1_1: C41.2, C44.1, U8.30 (VDD3_1)
/BM1370/VDD2_0: C32.2, C34.1, U8.2 (VDD2_0)
/BM1370/VDD2_1: C44.2, C46.1, U8.29 (VDD2_1)
/BM1370/VDD3_0: C28.2, C32.1, U8.3 (VDD1_0)
/BM1370/VDD3_1: C46.2, C48.1, U8.28 (VDD1_1)
/Fan/TEMP_N: U8.21 (TEMP_N); also elsewhere on the board
/Fan/TEMP_P: U8.20 (TEMP_P); also elsewhere on the board
/RST: U9.14 (B1); also elsewhere on the board
/RX: U9.12 (B3); also elsewhere on the board
/TX: U9.13 (B2); also elsewhere on the board
/VDD: C36.2, C37.1, C38.1, C39.1, C40.1, C41.1, C43.1, U8.31 (VDD); also elsewhere on the board
unnamed: TP21.1, U8.12 (INV_CLKO)
unnamed: C45.1, U8.17 (VDDIO_08_1)
unnamed: C42.1, U8.16 (VDDIO_12_1)
unnamed: R21.2, U9.9 (OE)

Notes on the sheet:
Reference Voltage Regulators
Direction Control HIGH= A -> B LOW = A <- B

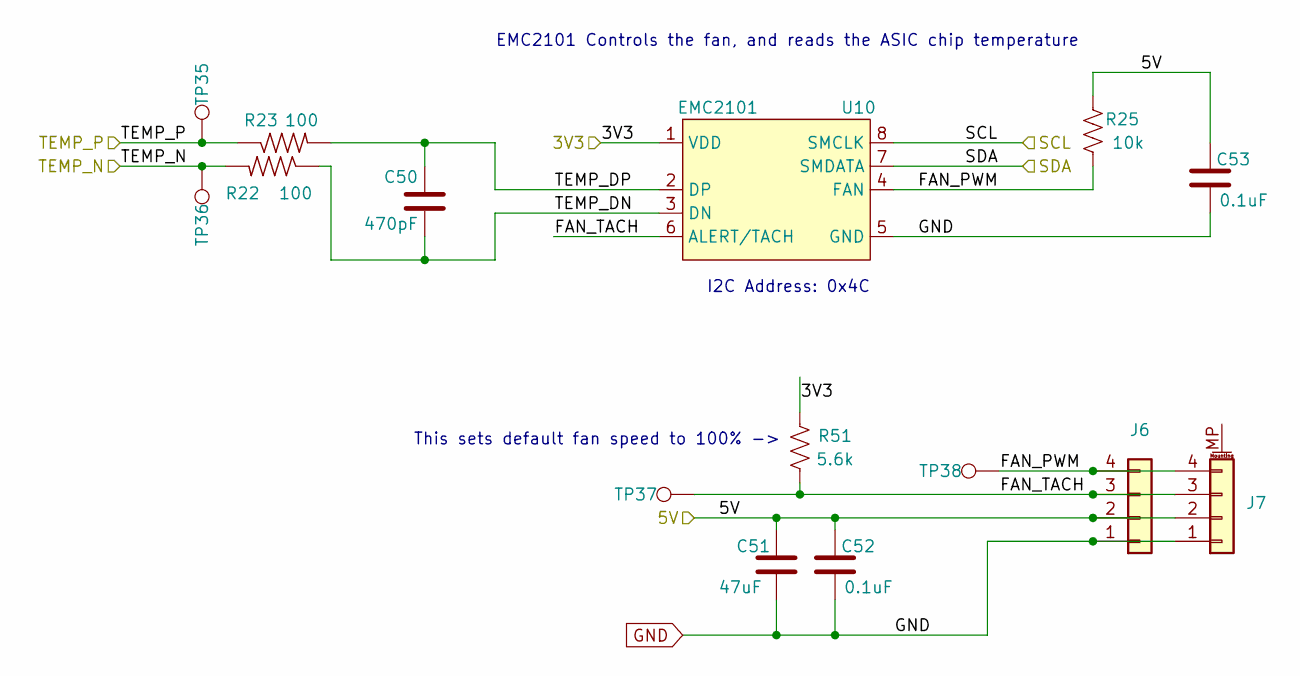
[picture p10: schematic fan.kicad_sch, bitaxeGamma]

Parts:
C50: 470pF; C_0402_1005Metric; PARTNO CL05B471KB5NNNC
C51: 47uF; C_1210_3225Metric; PARTNO CL32A476KOJNNNE
C52, C53: 0.1uF; C_0402_1005Metric; PARTNO CL05A104KO5NNNC
J6: Conn_01x04; 470531000; PARTNO 0470531000
J7: Conn_01x04; JST_SH_BM04B-SRSS-TB_1x04-1MP_P1.00mm_Vertical
R22, R23: 100; R_0402_1005Metric; PARTNO RC0402FR-07100RL
R25: 10k; R_0402_1005Metric; PARTNO RC0402JR-0710KL
R51: 5.6k; R_0402_1005Metric; PARTNO RC0402FR-135K6L
TP35, TP36, TP37, TP38: TestPoint; TestPoint_Pad_D1.5mm
U10: EMC2101; TSSOP-8_3x3mm_P0.65mm; PARTNO EMC2101-R-ACZL-TR

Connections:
/3V3: U10.1 (VDD); also elsewhere on the board
/5V: C51.1, C52.1, C53.1, J6.2, J7.2, R25.2; also elsewhere on the board
/Fan/FAN_PWM: J6.4, J7.4, R25.1, TP38.1, U10.4 (FAN)
/Fan/FAN_TACH: J6.3, J7.3, TP37.1, U10.6 (ALERT/TACH); also elsewhere on the board
/Fan/TEMP_DN: C50.2, R22.1, U10.3 (DN)
/Fan/TEMP_DP: C50.1, R23.2, U10.2 (DP)
/Fan/TEMP_N: R22.2, TP36.1; also elsewhere on the board
/Fan/TEMP_P: R23.1, TP35.1; also elsewhere on the board
/SCL: U10.8 (SMCLK); also elsewhere on the board
/SDA: U10.7 (SMDATA); also elsewhere on the board

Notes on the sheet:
EMC2101 Controls the fan, and reads the ASIC chip temperature
This sets default fan speed to 100% ->
I2C Address: 0x4C

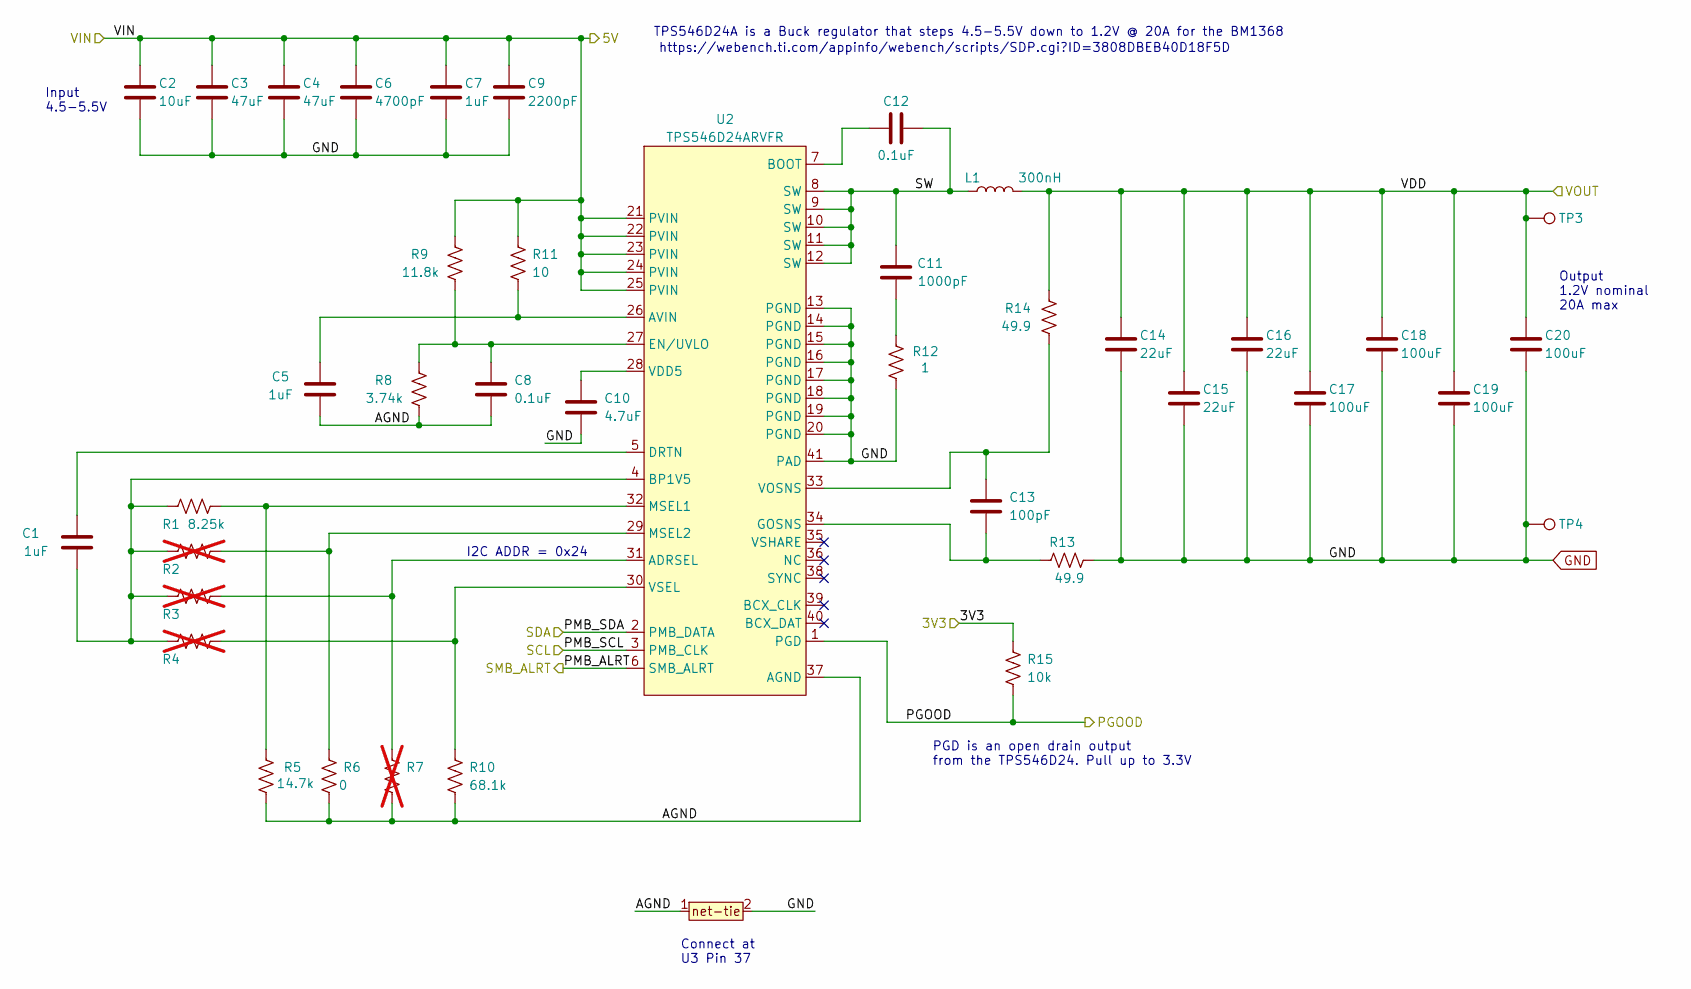
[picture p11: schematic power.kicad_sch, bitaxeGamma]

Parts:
C1, C5, C7: 1uF; C_0402_1005Metric; PARTNO EMK105BJ105MV-F
C2: 10uF; C_0805_2012Metric; PARTNO CL21A106KOQNNNE
C3, C4: 47uF; C_1210_3225Metric; PARTNO CL32A476KOJNNNE
C6: 4700pF; C_0402_1005Metric; PARTNO GRM155R71E472KA01D
C8, C12: 0.1uF; C_0402_1005Metric; PARTNO CL05A104KO5NNNC
C9: 2200pF; C_0402_1005Metric; PARTNO GRM155R61H222KA01D
C10: 4.7uF; C_0402_1005Metric; PARTNO GRM155R61A475MEAAD
C11: 1000pF; C_0805_2012Metric; PARTNO CC0805KRX7R9BB102
C13: 100pF; C_0402_1005Metric; PARTNO 885012005013
C14, C15, C16: 22uF; C_0805_2012Metric; PARTNO GRM21BR61A226ME44L
C17, C18, C19, C20: 100uF; C_1206_3216Metric; PARTNO CL31A107MQHNNNE
L1: 300nH; SLC1175-271MEC_COC; PARTNO SLC1175-301MEC; Mouser 994-SLC1175-271MEC
R1: 8.25k; R_0402_1005Metric; PARTNO RC0402FR-078K25L
R2, R3, R4, R7: R_0402_1005Metric; not fitted
R5: 14.7k; R_0402_1005Metric; PARTNO RC0402FR-0714K7L
R6: 0; R_0402_1005Metric; PARTNO RC0402JR-070RL
R8: 3.74k; R_0402_1005Metric; PARTNO RC0402FR-073K74L
R9: 11.8k; R_0402_1005Metric; PARTNO RC0402FR-0711K8L
R10: 68.1k; R_0402_1005Metric; PARTNO RC0402FR-0768K1L
R11: 10; R_0402_1005Metric; PARTNO RC0402FR-0710RL
R12: 1; R_1206_3216Metric; PARTNO CSR1206FT1R00
R13, R14: 49.9; R_0402_1005Metric; PARTNO RC0402FR-0749R9L
R15: 10k; R_0402_1005Metric; PARTNO RC0402JR-0710KL
T1: net-tie; NetTie-0.25mm
TP3, TP4: TestPoint; TestPoint_Pad_D1.5mm
U2: TPS546D24ARVFR; LQFN40-CLIP; PARTNO TPS546D24ARVFR

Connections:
/3V3: R15.2; also elsewhere on the board
/5V: C2.1, C3.1, C4.1, C6.1, C7.1, C9.1, R9.1, R11.1, U2.21 (PVIN), U2.22 (PVIN), U2.23 (PVIN), U2.24 (PVIN), U2.25 (PVIN); also elsewhere on the board
/Power/PGOOD: R15.1, U2.1 (PGD); also elsewhere on the board
/Power/PMB_ALRT: U2.6 (SMB_ALRT); also elsewhere on the board
/Power/SW: C11.2, C12.2, L1.1, U2.8 (SW), U2.9 (SW), U2.10 (SW), U2.11 (SW), U2.12 (SW)
/SCL: U2.3 (PMB_CLK); also elsewhere on the board
/SDA: U2.2 (PMB_DATA); also elsewhere on the board
/VDD: C14.1, C15.1, C16.1, C17.1, C18.1, C19.1, C20.1, L1.2, R14.1, TP3.1; also elsewhere on the board
unnamed: C11.1, R12.2
unnamed: R3.2, R7.1, U2.31 (ADRSEL)
unnamed: C5.2, R11.2, U2.26 (AVIN)
unnamed: C12.1, U2.7 (BOOT)
unnamed: C1.2, R1.1, R2.1, R3.1, R4.1, U2.4 (BP1V5)
unnamed: C1.1, U2.5 (DRTN)
unnamed: C8.1, R8.1, R9.2, U2.27 (EN/UVLO)
unnamed: C13.2, R13.1, U2.34 (GOSNS)
unnamed: R1.2, R5.2, U2.32 (MSEL1)
unnamed: C10.1, U2.28 (VDD5)
unnamed: C13.1, R14.2, U2.33 (VOSNS)
unnamed: R4.2, R10.1, U2.30 (VSEL)

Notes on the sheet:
TPS546D24A is a Buck regulator that steps 4.5-5.5V down to 1.2V @ 20A for the BM1368
https://webench.ti.com/appinfo/webench/scripts/SDP.cgi?ID=3808DBEB40D18F5D
Input 4.5-5.5V
PGD is an open drain output from the TPS546D24. Pull up to 3.3V
I2C ADDR = 0x24
Output 1.2V nominal 20A max
Connect at U3 Pin 37

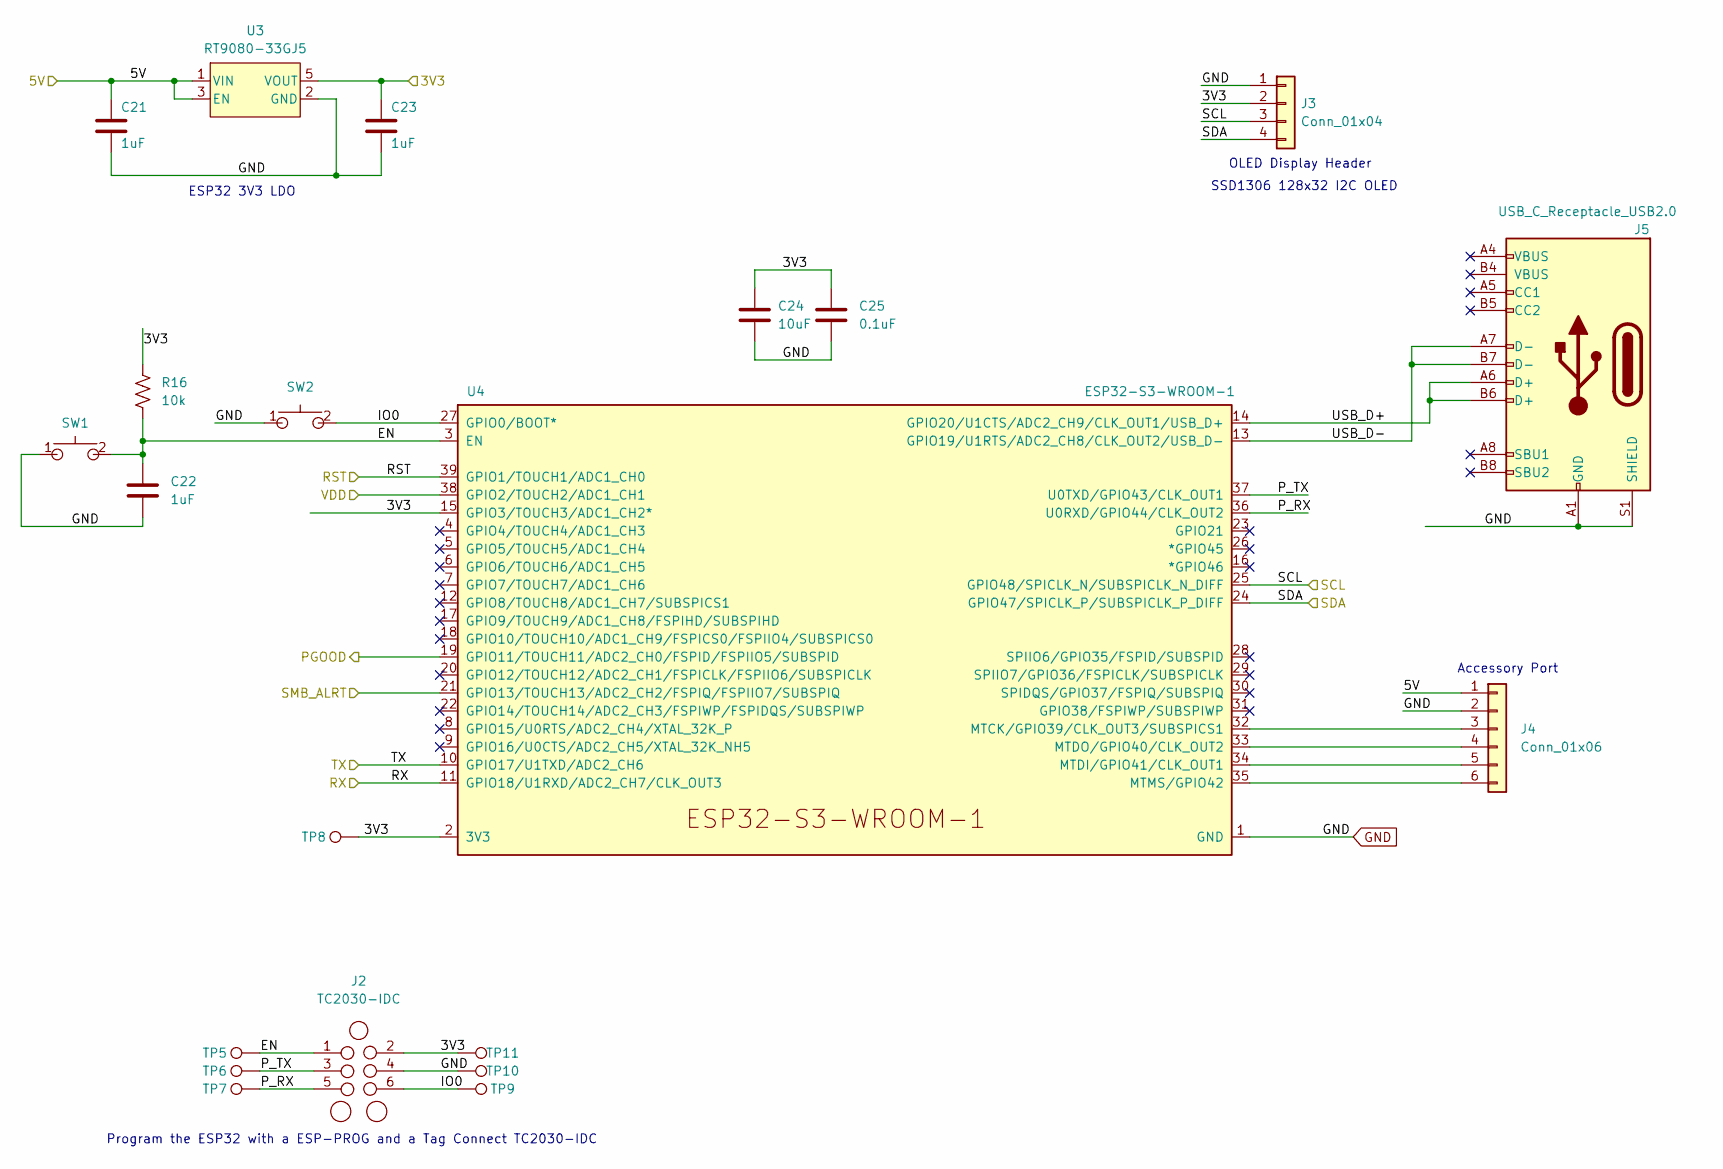
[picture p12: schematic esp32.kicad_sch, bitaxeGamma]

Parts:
C21, C22, C23: 1uF; C_0402_1005Metric; PARTNO EMK105BJ105MV-F
C24: 10uF; C_0805_2012Metric; PARTNO CL21A106KOQNNNE
C25: 0.1uF; C_0402_1005Metric; PARTNO CL05A104KO5NNNC
J2: TC2030-IDC; Tag-Connect_TC2030-IDC-NL_2x03_P1.27mm_Vertical
J3: Conn_01x04; PinHeader_1x04_P2.54mm_Vertical_shifted
J4: Conn_01x06; PinHeader_1x06_P2.54mm_Vertical
J5: USB_C_Receptacle_USB2.0; USB_C_Receptacle_GCT_USB4105-xx-A; PARTNO USB4105-GF-A
R16: 10k; R_0402_1005Metric; PARTNO RC0402JR-0710KL
SW1, SW2: GT-TC029B-H025-L1N; SW_CS1213AGF260_CRS; PARTNO CS1213AGF260
TP5, TP6, TP7, TP8, TP9, TP10, TP11: TestPoint; TestPoint_Pad_D1.5mm
U3: RT9080-33GJ5; PARTNO RT9080-33GJ5
U4: ESP32-S3-WROOM-1; PARTNO ESP32-S3-WROOM-1-N16R8

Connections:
/3V3: C23.1, C24.1, C25.1, J2.2, J3.2, R16.1, TP8.1, TP11.1, U3.5 (VOUT), U4.2 (3V3), U4.15 (GPIO3/TOUCH3/ADC1_CH2*); also elsewhere on the board
/5V: C21.1, J4.1, U3.1 (VIN), U3.3 (EN); also elsewhere on the board
/ESP32/EN: C22.1, J2.1, R16.2, SW1.2, TP5.1, U4.3 (EN)
/ESP32/IO0: J2.6, SW2.2, TP9.1, U4.27 (GPIO0/BOOT*)
/ESP32/P_RX: J2.5, TP7.1, U4.36 (U0RXD/GPIO44/CLK_OUT2)
/ESP32/P_TX: J2.3, TP6.1, U4.37 (U0TXD/GPIO43/CLK_OUT1)
/ESP32/USB_D+: J5.A6 (D+), J5.B6 (D+), U4.14 (GPIO20/U1CTS/ADC2_CH9/CLK_OUT1/USB_D+)
/ESP32/USB_D-: J5.A7 (D-), J5.B7 (D-), U4.13 (GPIO19/U1RTS/ADC2_CH8/CLK_OUT2/USB_D-)
/Power/PGOOD: U4.19 (GPIO11/TOUCH11/ADC2_CH0/FSPID/FSPIIO5/S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); also elsewhere on the board
/Power/PMB_ALRT: U4.21 (GPIO13/TOUCH13/ADC2_CH2/FSPIQ/FSPIIO7/S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); also elsewhere on the board
/RST: U4.39 (GPIO1/TOUCH1/ADC1_CH0); also elsewhere on the board
/RX: U4.11 (GPIO18/U1RXD/ADC2_CH7/CLK_OUT3); also elsewhere on the board
/SCL: J3.3, U4.25 (GPIO48/SPICLK_N/SUBSPICLK_N_DIFF); also elsewhere on the board
/SDA: J3.4, U4.24 (GPIO47/SPICLK_P/SUBSPICLK_P_DIFF); also elsewhere on the board
/TX: U4.10 (GPIO17/U1TXD/ADC2_CH6); also elsewhere on the board
/VDD: U4.38 (GPIO2/TOUCH2/ADC1_CH1); also elsewhere on the board
unnamed: J4.3, U4.32 (MTCK/GPIO39/CLK_OUT3/SUBSPICS1)
unnamed: J4.4, U4.33 (MTDO/GPIO40/CLK_OUT2)
unnamed: J4.5, U4.34 (MTDI/GPIO41/CLK_OUT1)
unnamed: J4.6, U4.35 (MTMS/GPIO42)

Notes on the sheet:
Accessory Port
ESP32 3V3 LDO
Program the ESP32 with a ESP-PROG and a Tag Connect TC2030-IDC
SSD1306 128x32 I2C OLED
OLED Display Header

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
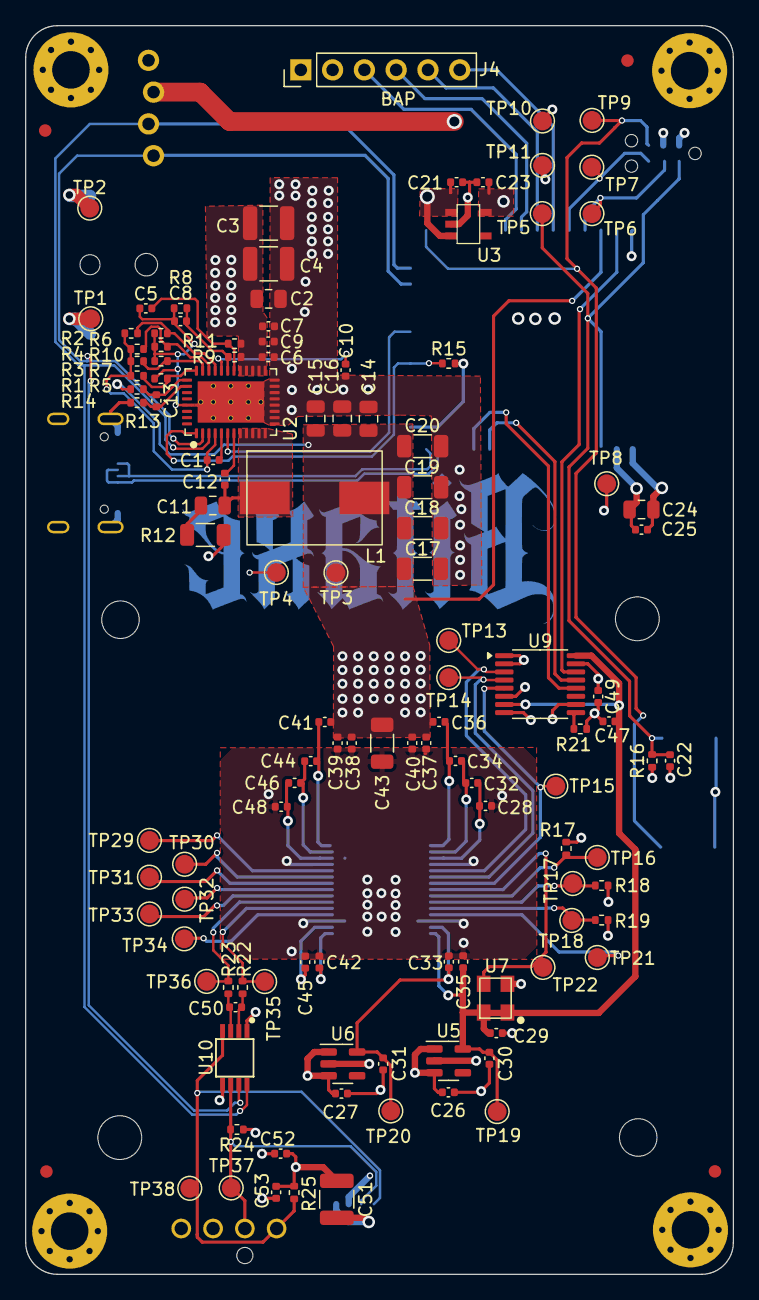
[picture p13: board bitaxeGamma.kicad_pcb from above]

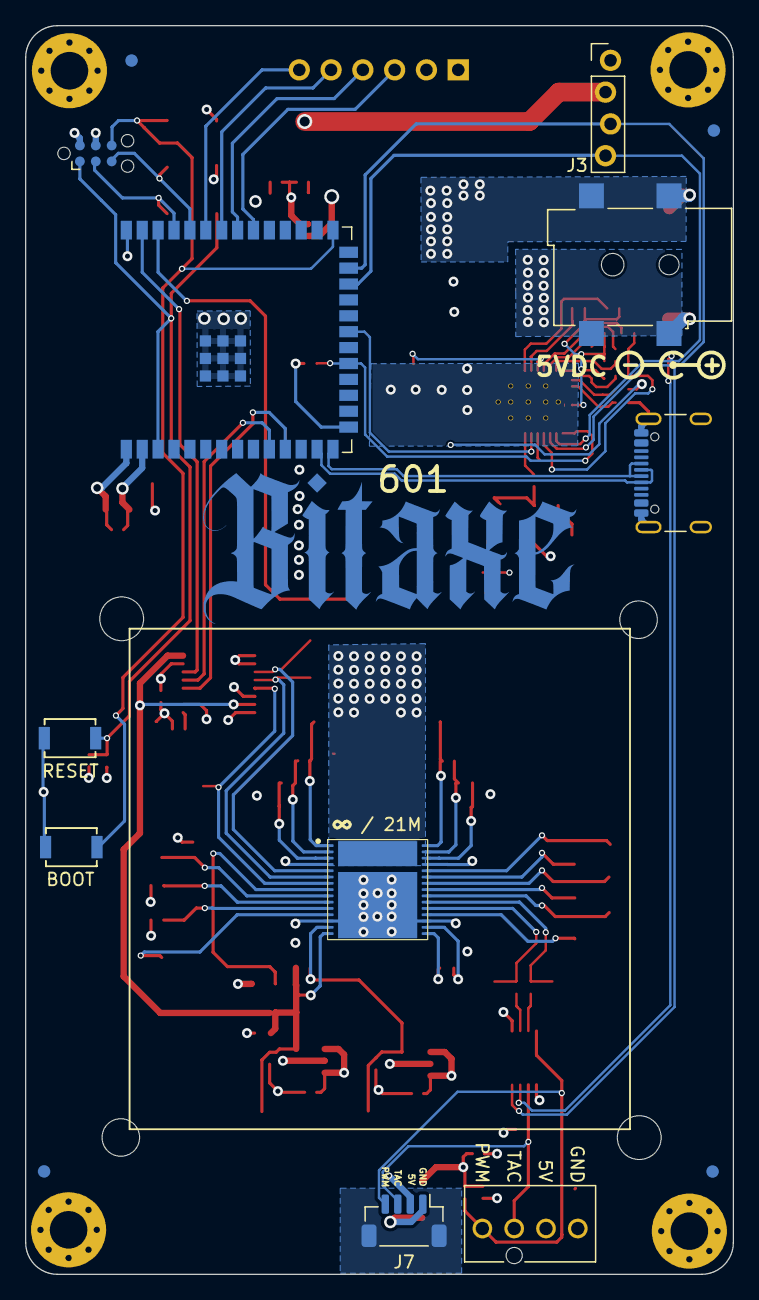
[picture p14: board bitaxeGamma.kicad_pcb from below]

Board: 4 copper layers, 56.5 x 99.8 mm, 145 parts (15 on the bottom side), 67 nets.

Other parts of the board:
R17: 10k; R_0402_1005Metric
R18, R19: 1k; R_0402_1005Metric
R24: 5.6k; R_0402_1005Metric

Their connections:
/3V3: R24.2; also elsewhere on the board
/Fan/FAN_TACH: R24.1; also elsewhere on the board

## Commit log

2024-07-02 switching to gamma/600 naming
    [bitaxeGamma.kicad_pcb, bitaxeGamma.kicad_sch, bitaxeSupra BOM.csv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]
2024-07-03 added BM1370 footprint
    [bitaxeGamma.kicad_pcb, bm1370.kicad_sch]
2024-07-03 added gerbers, BOM, updated readme and render
    [bitaxeGamma BOM.csv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]
2024-07-03 BOM update
    [bitaxeGamma BOM.csv, bm1370.kicad_sch, power.kicad_sch]
2024-07-05 fix oscillator name
    [bitaxeGamma.kicad_pcb, bm1370.kicad_sch]
2024-08-16 bump version to 600
    [bitaxeGamma-B_Cu.gbr, bitaxeGamma-B_Mask.gbr, bitaxeGamma-B_Paste.gbr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]
2024-08-19 add schematic pdf
2024-08-20 JST fan connector
    [BM04B-SRSS-TBT(LF)(SN)--3DModel-STEP-56544.STEP, bitaxeGamma.kicad_pcb, bitaxeGamma.kicad_sch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]
2024-08-20 better fan routing
    [bitaxeGamma.kicad_pcb]
2024-08-21 fan routing and MP anchor
    [bitaxeGamma.kicad_pcb]
2024-09-19 remove J3 from BOM for #2
    [bitaxeGamma BOM.csv, esp32.kicad_sch]
2024-09-26 remove old gerbers
    [bitaxeGamma-B_Cu.gbr, bitaxeGamma-B_Mask.gbr, bitaxeGamma-B_Paste.gbr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]
2024-09-26 bump version to 602. remove R21 and fix for #6
    [bitaxeGamma.kicad_pcb, bitaxeGamma.kicad_sch, bm1370.kicad_sch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]
2024-09-26 Revert "bump version to 602. remove R21 and fix for #6"
    This reverts commit 8bd74c865f9910776743c8aa45b35babe35214af.
    [bitaxeGamma.kicad_pcb, bitaxeGamma.kicad_sch, bm1370.kicad_sch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]
2024-10-10 fix typos in BOM. Improve BOM generator output
    [bitaxeGamma BOM.csv, bitaxeGamma-BOM.csv, bm1370.kicad_sch]
2024-11-26 added 601 gerbers, BOM and iBOM
    [bitaxeGamma BOM.csv, bitaxeGamma-BOM.csv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]
2024-11-26 update schematic PDF
